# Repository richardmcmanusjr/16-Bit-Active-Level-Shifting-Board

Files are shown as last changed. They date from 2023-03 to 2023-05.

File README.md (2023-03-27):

# 16-Bit-Active-Level-Shifting-Board

This repository contains a 16-bit active level shifting board designed to interface a 16-bit adiabatic MIPS with a Virtex-7 VC707 FPGA. Active level shifting was required to convert the FPGA's 0 to +1.8V logic to the microprocessor's -0.6 to +0.6V logic. Comparators and a direction control unit was chosen for this purpose.

# Details

Schematic File:
  - 1-bit level shifting design block replicated 16 times
  - Power design block for regulated +/-1.5V and +3V
  - Direction controlling design block
  
Board File:
  - 2 layer board
  - 2 columns of 8 level shifting design blocks
  - 24-pin Molex ribbon cable connectors for input/output
  
# Design

### 1-Bit Active Level Shifter
<p align="center">
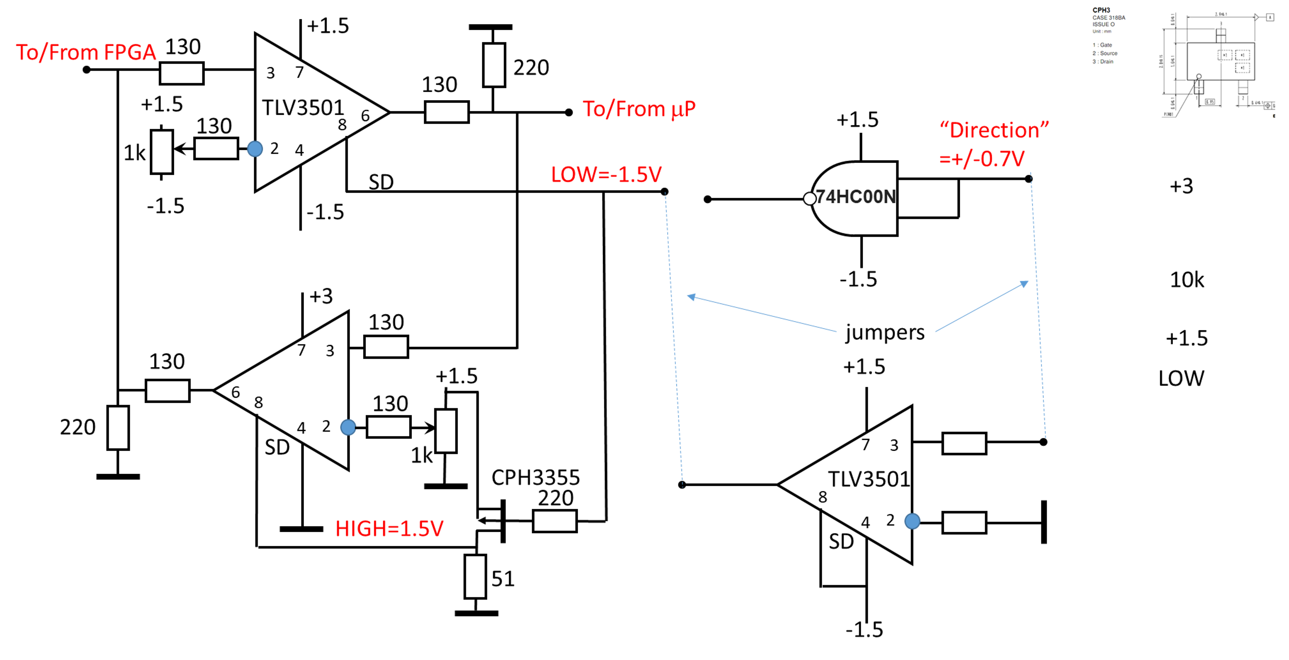
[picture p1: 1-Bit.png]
  
</p>

# Layout 

### mainboard-01-8x2+1c.brd
<p align="center">
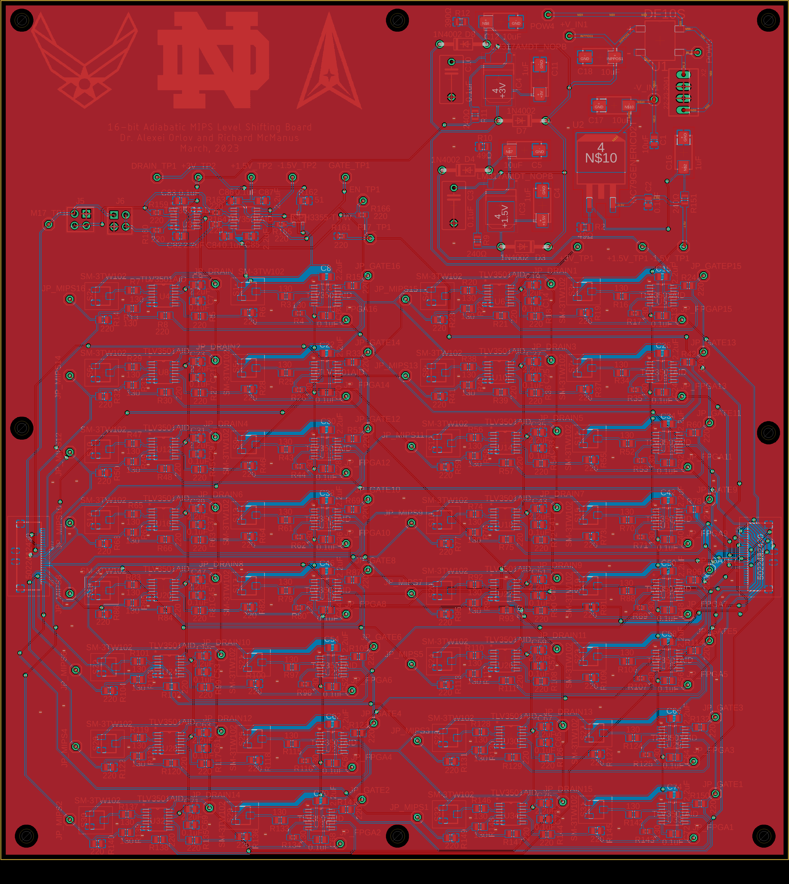
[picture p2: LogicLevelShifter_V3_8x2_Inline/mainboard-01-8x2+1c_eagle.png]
  
</p>

### mainboard-01-8x2+1c OSHPARK
<p align="center">
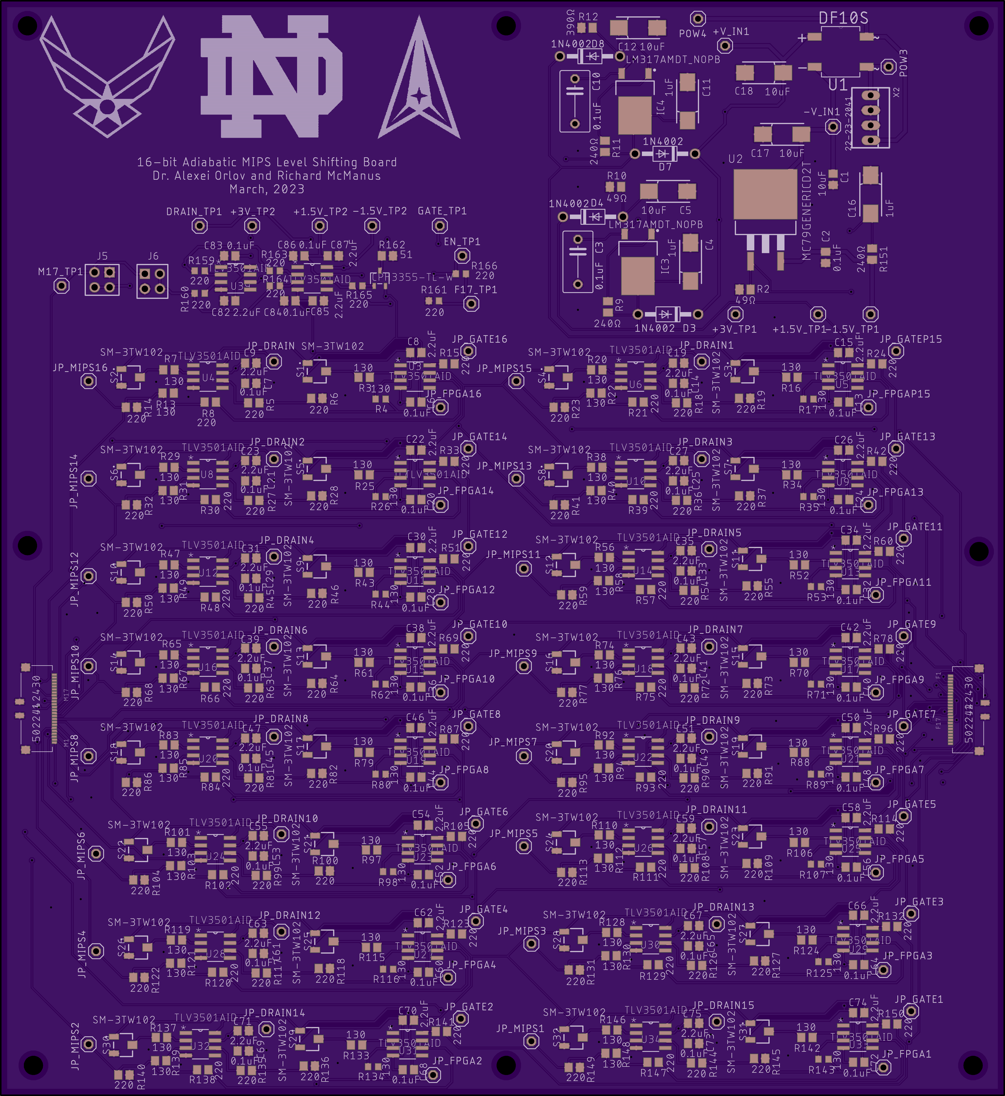
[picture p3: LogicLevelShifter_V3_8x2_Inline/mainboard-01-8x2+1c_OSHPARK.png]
  
</p>

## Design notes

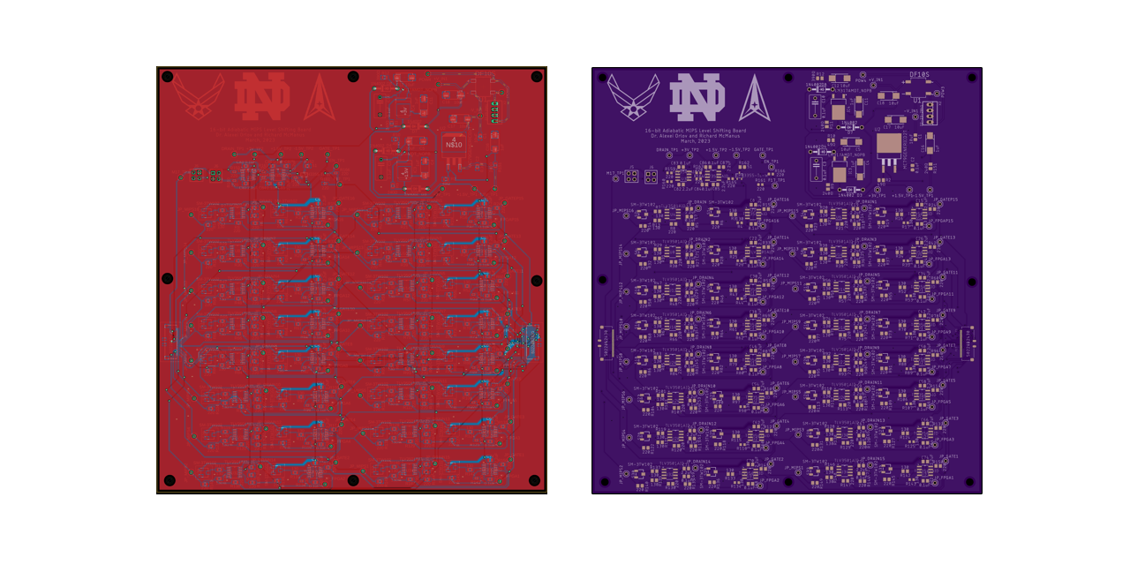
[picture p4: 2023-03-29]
preview.png

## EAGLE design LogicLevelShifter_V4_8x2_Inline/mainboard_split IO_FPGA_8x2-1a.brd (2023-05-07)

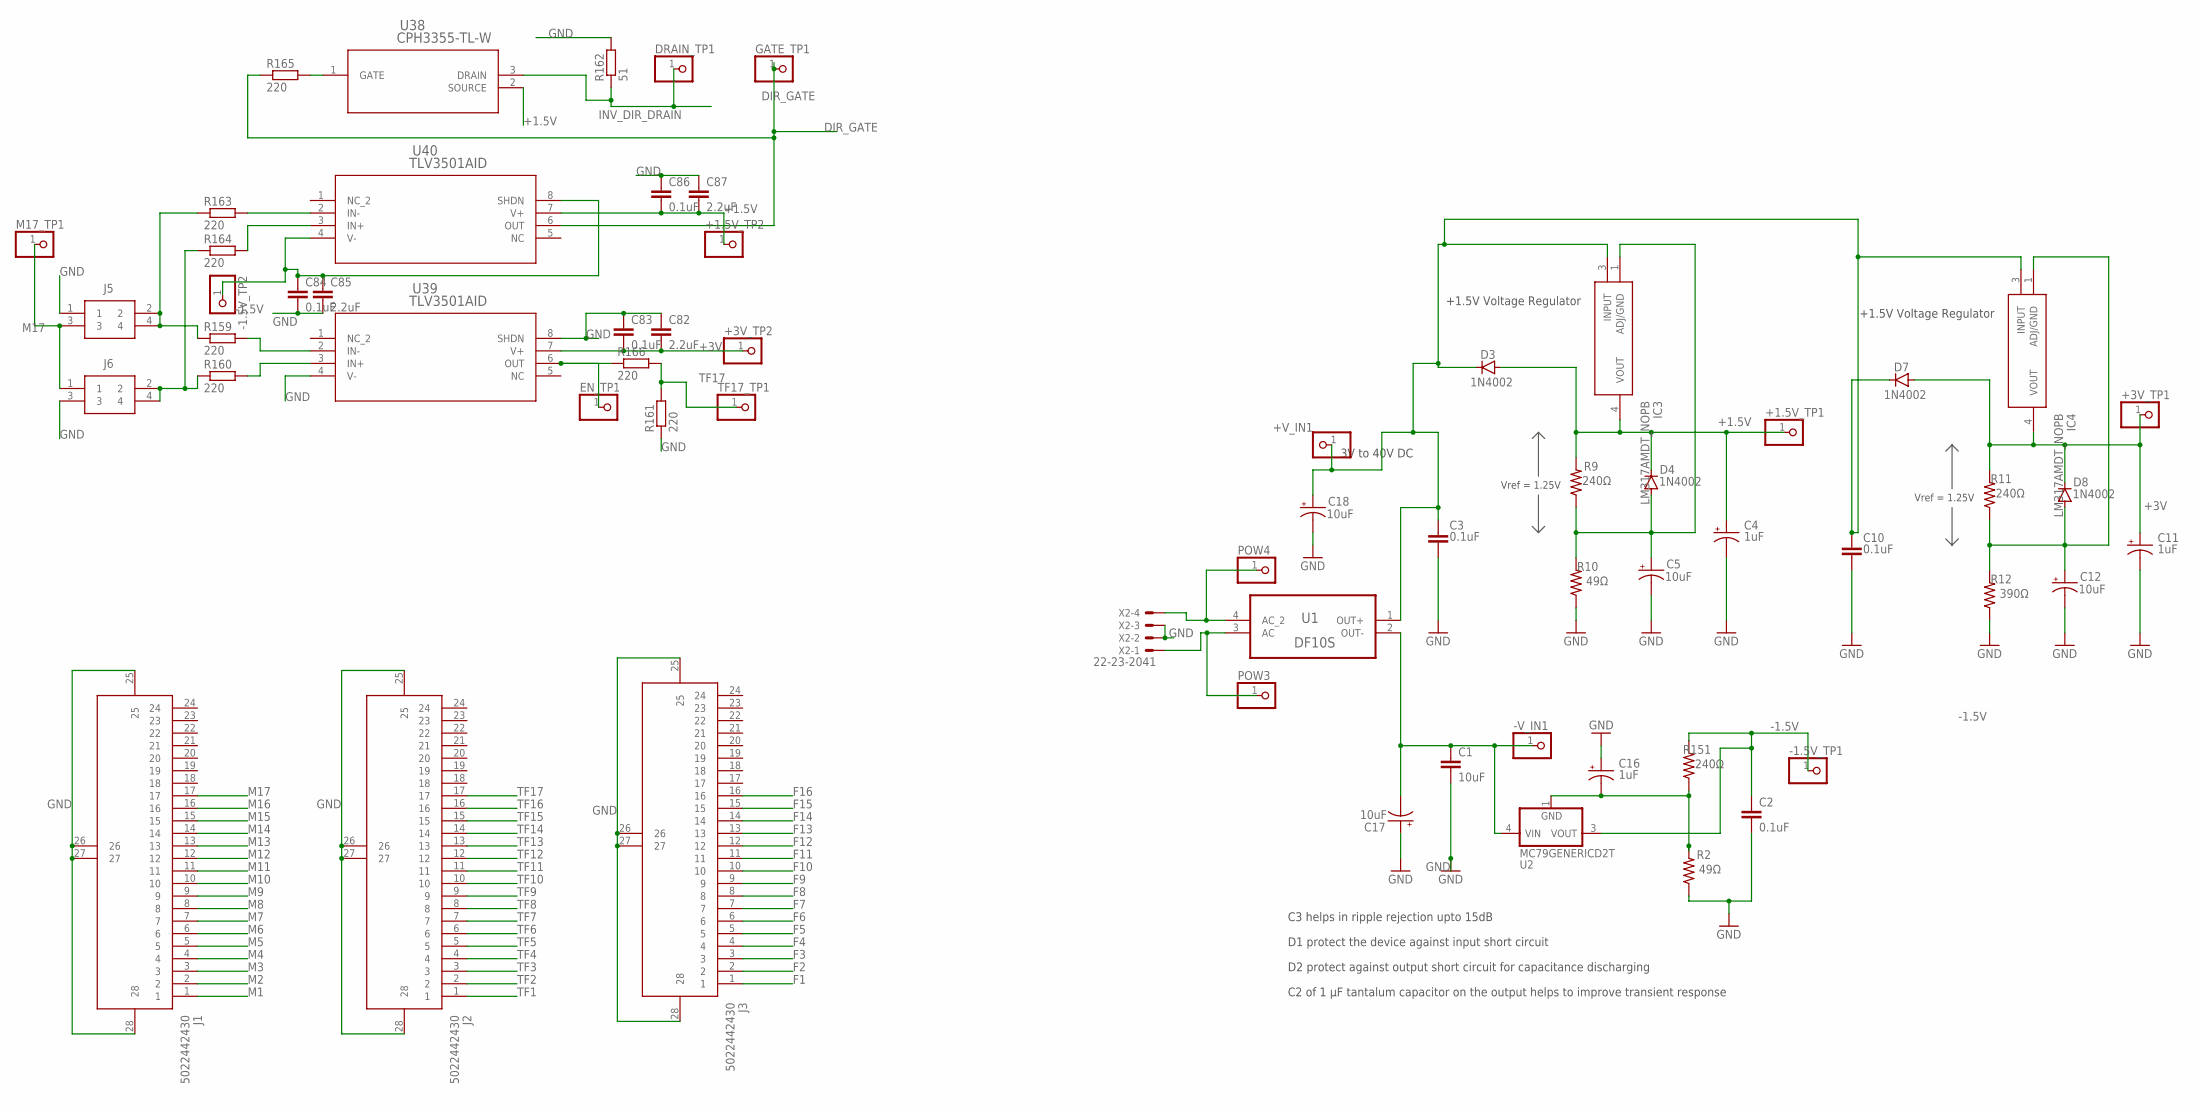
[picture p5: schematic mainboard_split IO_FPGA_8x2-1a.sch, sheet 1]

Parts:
+1.5V_TP1, +1.5V_TP2, +3V_TP1, +3V_TP2: PINHD-1X1; 1X01
+V_IN1: PINHD-1X1; 1X01
-1.5V_TP1, -1.5V_TP2: PINHD-1X1; 1X01
-V_IN1: PINHD-1X1; 1X01
C1: 10uF; C0805
C2, C83, C84, C86: 0.1uF; C0805
C3, C10: 0.1uF; C075-052X106
C4, C11, C16: 1uF; 085CS_1AR
C5, C12, C17, C18: 10uF; 085CS_1AR
C82, C85, C87: 2.2uF; C0805
D3, D4, D7, D8: 1N4002; DO41-10
DRAIN_TP1: PINHD-1X1; 1X01
EN_TP1: PINHD-1X1; 1X01
GATE_TP1: PINHD-1X1; 1X01
IC3, IC4: LM317AMDT_NOPB; TO228P991X238-3N
J1, J2, J3: 5022442430
J5, J6: 70287-1098; HDRV4W64P254_2X2_521X508X851P
M17_TP1: PINHD-1X1; 1X01
POW3, POW4: PINHD-1X1; 1X01
R2, R10: 49Ω; M0805
R9, R11, R151: 240Ω; M0805
R12: 390Ω; M0805
R159, R160, R161, R163, R164, R165, R166: 220; R0603
R162: 51; R0805
TF17_TP1: PINHD-1X1; 1X01
U1: DF10S; SOT508P985X260-4N
U2: MC79GENERICD2T; D2PAK-3
U38: CPH3355-TL-W; CPH3_2P9X1P6_ONS
U39, U40: TLV3501AID; D8
X2: 22-23-2041

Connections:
+1.5V: +1.5V_TP1.1, +1.5V_TP2.1, C4.+, C86.2, C87.2, D3.A, D4.C, IC3.4 (VOUT), R9.2, U38.2 (SOURCE), U40.7 (V+); also elsewhere on the board
+3V: +3V_TP1.1, +3V_TP2.1, C11.+, C82.2, C83.2, D7.A, D8.C, IC4.4 (VOUT), R11.2, U39.7 (V+); also elsewhere on the board
-1.5V: -1.5V_TP1.1, -1.5V_TP2.1, C2.1, C84.1, C85.1, R151.2, U2.3 (VOUT), U40.4 (V-), U40.8 (SHDN); also elsewhere on the board
DIR_GATE: GATE_TP1.1, R165.1, U40.6 (OUT); also elsewhere on the board
F1: J3.1; also elsewhere on the board
F2: J3.2; also elsewhere on the board
F3: J3.3; also elsewhere on the board
F4: J3.4; also elsewhere on the board
F5: J3.5; also elsewhere on the board
F6: J3.6; also elsewhere on the board
F7: J3.7; also elsewhere on the board
F8: J3.8; also elsewhere on the board
F9: J3.9; also elsewhere on the board
F10: J3.10; also elsewhere on the board
F11: J3.11; also elsewhere on the board
F12: J3.12; also elsewhere on the board
F13: J3.13; also elsewhere on the board
F14: J3.14; also elsewhere on the board
F15: J3.15; also elsewhere on the board
F16: J3.16; also elsewhere on the board
GND: C1.2, C2.2, C3.2, C4.-, C5.-, C10.2, C11.-, C12.-, C16.+, C17.+, C18.-, C82.1, C83.1, C84.2, C85.2, C86.1, C87.1, J1.25, J1.26, J1.27, J1.28, J2.25, J2.26, J2.27, J2.28, J3.25, J3.26, J3.27, J3.28, J5.1, J6.3, R2.1, R10.1, R12.1, R161.1, R162.2, U39.4 (V-), U39.8 (SHDN), X2.2, X2.3; also elsewhere on the board
INPPOS1: +V_IN1.1, C3.1, C10.1, C18.+, D3.C, D7.C, IC3.3 (INPUT), IC4.3 (INPUT), U1.1 (OUT+)
INV_DIR_DRAIN: DRAIN_TP1.1, R162.1, U38.3 (DRAIN); also elsewhere on the board
IN_2: POW3.1, U1.3 (AC), X2.1
M1: J1.1; also elsewhere on the board
M2: J1.2; also elsewhere on the board
M3: J1.3; also elsewhere on the board
M4: J1.4; also elsewhere on the board
M5: J1.5; also elsewhere on the board
M6: J1.6; also elsewhere on the board
M7: J1.7; also elsewhere on the board
M8: J1.8; also elsewhere on the board
M9: J1.9; also elsewhere on the board
M10: J1.10; also elsewhere on the board
M11: J1.11; also elsewhere on the board
M12: J1.12; also elsewhere on the board
M13: J1.13; also elsewhere on the board
M14: J1.14; also elsewhere on the board
M15: J1.15; also elsewhere on the board
M16: J1.16; also elsewhere on the board
M17: J1.17, J5.3, J6.1, M17_TP1.1
unnamed: C16.-, R2.2, R151.1, U2.1 (GND)
unnamed: C5.+, D4.A, IC3.1 (ADJ/GND), R9.1, R10.2
unnamed: C12.+, D8.A, IC4.1 (ADJ/GND), R11.1, R12.2
unnamed: POW4.1, U1.4 (AC_2), X2.4
unnamed: -V_IN1.1, C1.1, C17.-, U1.2 (OUT-), U2.4 (VIN)
unnamed: R159.2, U39.2 (IN-)
unnamed: R160.2, U39.3 (IN+)
unnamed: EN_TP1.1, R166.1, U39.6 (OUT)
unnamed: J6.2, J6.4, R160.1, R164.1
unnamed: J5.2, J5.4, R159.1, R163.1
unnamed: R163.2, U40.2 (IN-)
unnamed: R164.2, U40.3 (IN+)
unnamed: R165.2, U38.1 (GATE)
TF1: J2.1; also elsewhere on the board
TF2: J2.2; also elsewhere on the board
TF3: J2.3; also elsewhere on the board
TF4: J2.4; also elsewhere on the board
TF5: J2.5; also elsewhere on the board
TF6: J2.6; also elsewhere on the board
TF7: J2.7; also elsewhere on the board
TF8: J2.8; also elsewhere on the board
TF9: J2.9; also elsewhere on the board
TF10: J2.10; also elsewhere on the board
TF11: J2.11; also elsewhere on the board
TF12: J2.12; also elsewhere on the board
TF13: J2.13; also elsewhere on the board
TF14: J2.14; also elsewhere on the board
TF15: J2.15; also elsewhere on the board
TF16: J2.16; also elsewhere on the board
TF17: J2.17, R161.2, R166.2, TF17_TP1.1

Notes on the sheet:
+1.5V Voltage Regulator
3V to 40V DC
Vref = 1.25V
C3 helps in ripple rejection upto 15dB
D1 protect the device against input short circuit
D2 protect against output short circuit for capacitance discharging
C2 of 1 µF tantalum capacitor on the output helps to improve transient response

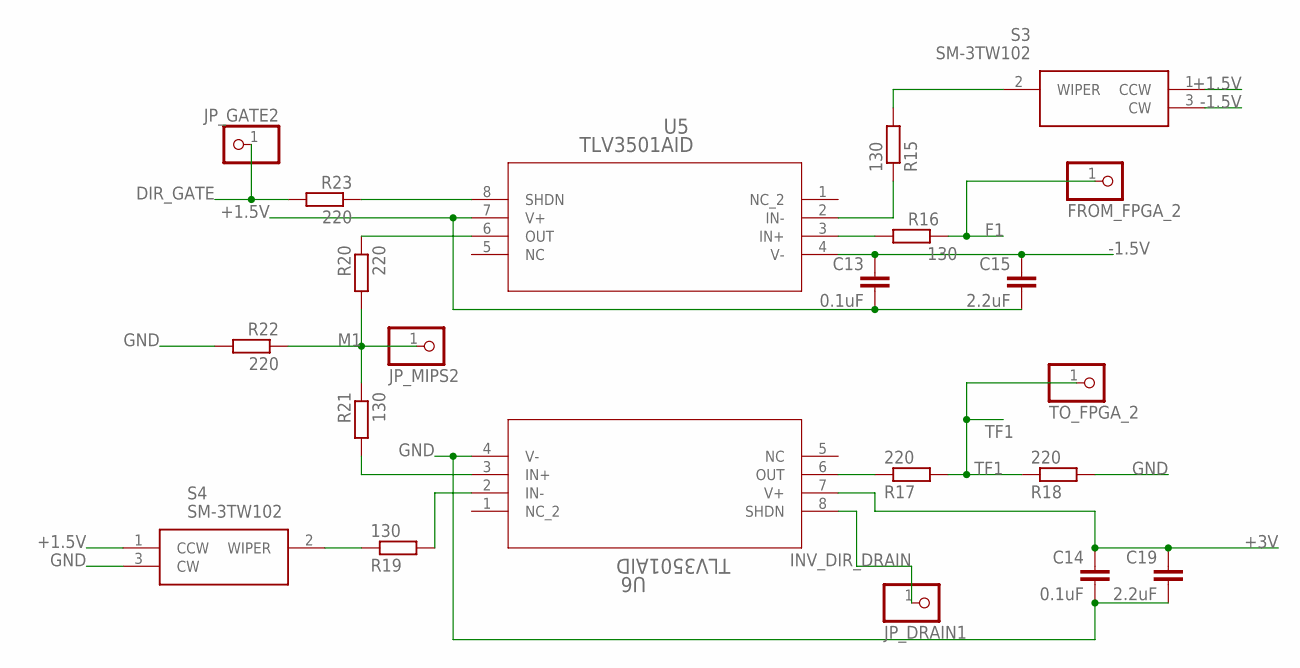
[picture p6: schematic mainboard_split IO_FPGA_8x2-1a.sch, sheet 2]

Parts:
C13, C14: 0.1uF; C0805
C15, C19: 2.2uF; C0805
FROM_FPGA_2: PINHD-1X1; 1X01
JP_DRAIN1: PINHD-1X1; 1X01
JP_GATE2: PINHD-1X1; 1X01
JP_MIPS2: PINHD-1X1; 1X01
R15, R19, R21: 130; R0805
R16: 130; R0603
R17, R18, R20, R22, R23: 220; R0805
S3, S4: SM-3TW102; SM3TW102
TO_FPGA_2: PINHD-1X1; 1X01
U5, U6: TLV3501AID; D8

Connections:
+1.5V: C13.2, C15.2, S3.1 (CCW), S4.1 (CCW), U5.7 (V+); also elsewhere on the board
+3V: C14.1, C19.1, U6.7 (V+); also elsewhere on the board
-1.5V: C13.1, C15.1, S3.3 (CW), U5.4 (V-); also elsewhere on the board
DIR_GATE: JP_GATE2.1, R23.2; also elsewhere on the board
F1: FROM_FPGA_2.1, R16.1; also elsewhere on the board
GND: C14.2, C19.2, R18.2, R22.2, S4.3 (CW), U6.4 (V-); also elsewhere on the board
INV_DIR_DRAIN: JP_DRAIN1.1, U6.8 (SHDN); also elsewhere on the board
M1: JP_MIPS2.1, R20.2, R21.1, R22.1; also elsewhere on the board
unnamed: R15.2, S3.2 (WIPER)
unnamed: R15.1, U5.2 (IN-)
unnamed: R17.1, U6.6 (OUT)
unnamed: R19.1, S4.2 (WIPER)
unnamed: R19.2, U6.2 (IN-)
unnamed: R21.2, U6.3 (IN+)
unnamed: R20.1, U5.6 (OUT)
unnamed: R23.1, U5.8 (SHDN)
unnamed: R16.2, U5.3 (IN+)
TF1: R17.2, R18.1, TO_FPGA_2.1; also elsewhere on the board

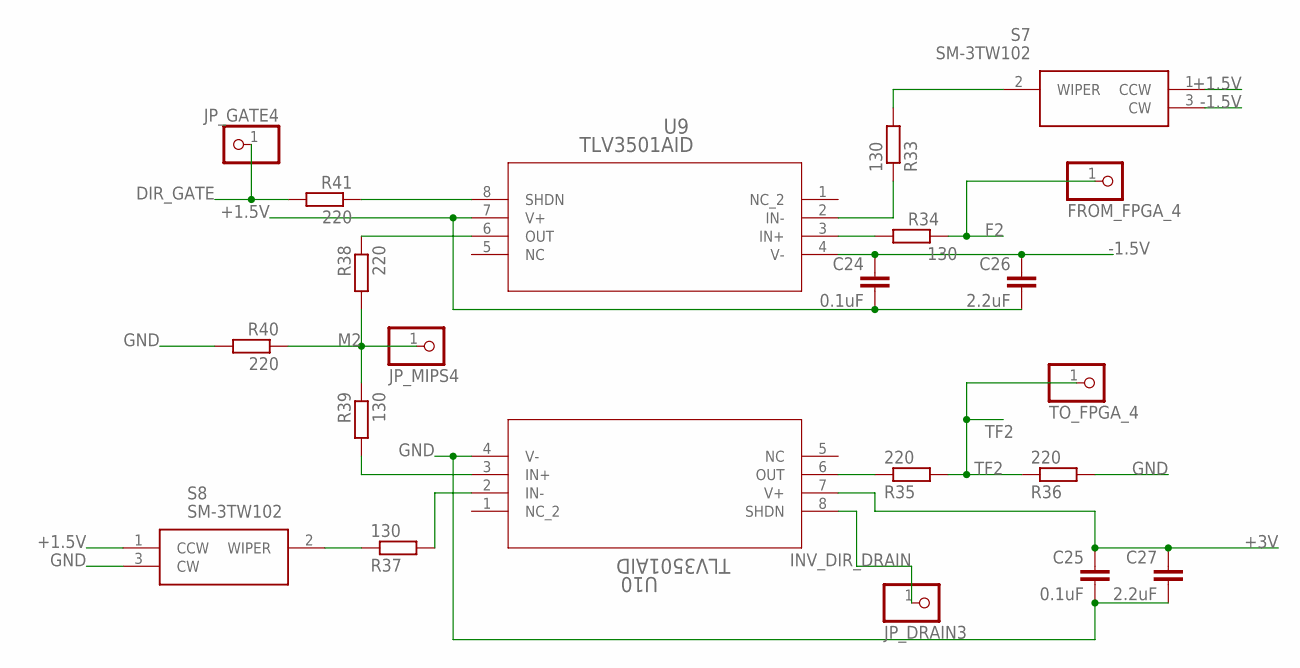
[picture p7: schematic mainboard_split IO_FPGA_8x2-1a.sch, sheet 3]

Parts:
C24, C25: 0.1uF; C0805
C26, C27: 2.2uF; C0805
FROM_FPGA_4: PINHD-1X1; 1X01
JP_DRAIN3: PINHD-1X1; 1X01
JP_GATE4: PINHD-1X1; 1X01
JP_MIPS4: PINHD-1X1; 1X01
R33, R37, R39: 130; R0805
R34: 130; R0603
R35, R36, R38, R40, R41: 220; R0805
S7, S8: SM-3TW102; SM3TW102
TO_FPGA_4: PINHD-1X1; 1X01
U9, U10: TLV3501AID; D8

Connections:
+1.5V: C24.2, C26.2, S7.1 (CCW), S8.1 (CCW), U9.7 (V+); also elsewhere on the board
+3V: C25.1, C27.1, U10.7 (V+); also elsewhere on the board
-1.5V: C24.1, C26.1, S7.3 (CW), U9.4 (V-); also elsewhere on the board
DIR_GATE: JP_GATE4.1, R41.2; also elsewhere on the board
F2: FROM_FPGA_4.1, R34.1; also elsewhere on the board
GND: C25.2, C27.2, R36.2, R40.2, S8.3 (CW), U10.4 (V-); also elsewhere on the board
INV_DIR_DRAIN: JP_DRAIN3.1, U10.8 (SHDN); also elsewhere on the board
M2: JP_MIPS4.1, R38.2, R39.1, R40.1; also elsewhere on the board
unnamed: R33.2, S7.2 (WIPER)
unnamed: R33.1, U9.2 (IN-)
unnamed: R35.1, U10.6 (OUT)
unnamed: R37.1, S8.2 (WIPER)
unnamed: R37.2, U10.2 (IN-)
unnamed: R39.2, U10.3 (IN+)
unnamed: R38.1, U9.6 (OUT)
unnamed: R41.1, U9.8 (SHDN)
unnamed: R34.2, U9.3 (IN+)
TF2: R35.2, R36.1, TO_FPGA_4.1; also elsewhere on the board

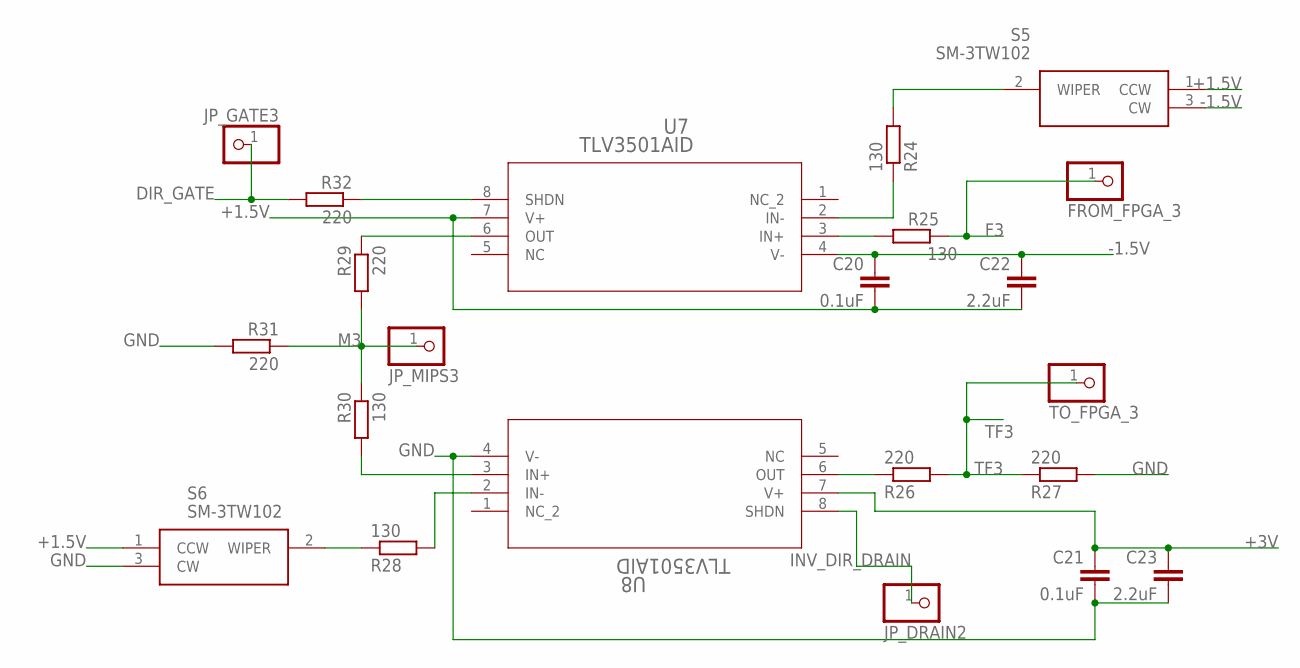
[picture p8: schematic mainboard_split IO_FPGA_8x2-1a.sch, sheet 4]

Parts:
C20, C21: 0.1uF; C0805
C22, C23: 2.2uF; C0805
FROM_FPGA_3: PINHD-1X1; 1X01
JP_DRAIN2: PINHD-1X1; 1X01
JP_GATE3: PINHD-1X1; 1X01
JP_MIPS3: PINHD-1X1; 1X01
R24, R28, R30: 130; R0805
R25: 130; R0603
R26, R27, R29, R31, R32: 220; R0805
S5, S6: SM-3TW102; SM3TW102
TO_FPGA_3: PINHD-1X1; 1X01
U7, U8: TLV3501AID; D8

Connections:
+1.5V: C20.2, C22.2, S5.1 (CCW), S6.1 (CCW), U7.7 (V+); also elsewhere on the board
+3V: C21.1, C23.1, U8.7 (V+); also elsewhere on the board
-1.5V: C20.1, C22.1, S5.3 (CW), U7.4 (V-); also elsewhere on the board
DIR_GATE: JP_GATE3.1, R32.2; also elsewhere on the board
F3: FROM_FPGA_3.1, R25.1; also elsewhere on the board
GND: C21.2, C23.2, R27.2, R31.2, S6.3 (CW), U8.4 (V-); also elsewhere on the board
INV_DIR_DRAIN: JP_DRAIN2.1, U8.8 (SHDN); also elsewhere on the board
M3: JP_MIPS3.1, R29.2, R30.1, R31.1; also elsewhere on the board
unnamed: R24.2, S5.2 (WIPER)
unnamed: R24.1, U7.2 (IN-)
unnamed: R26.1, U8.6 (OUT)
unnamed: R28.1, S6.2 (WIPER)
unnamed: R28.2, U8.2 (IN-)
unnamed: R30.2, U8.3 (IN+)
unnamed: R29.1, U7.6 (OUT)
unnamed: R32.1, U7.8 (SHDN)
unnamed: R25.2, U7.3 (IN+)
TF3: R26.2, R27.1, TO_FPGA_3.1; also elsewhere on the board

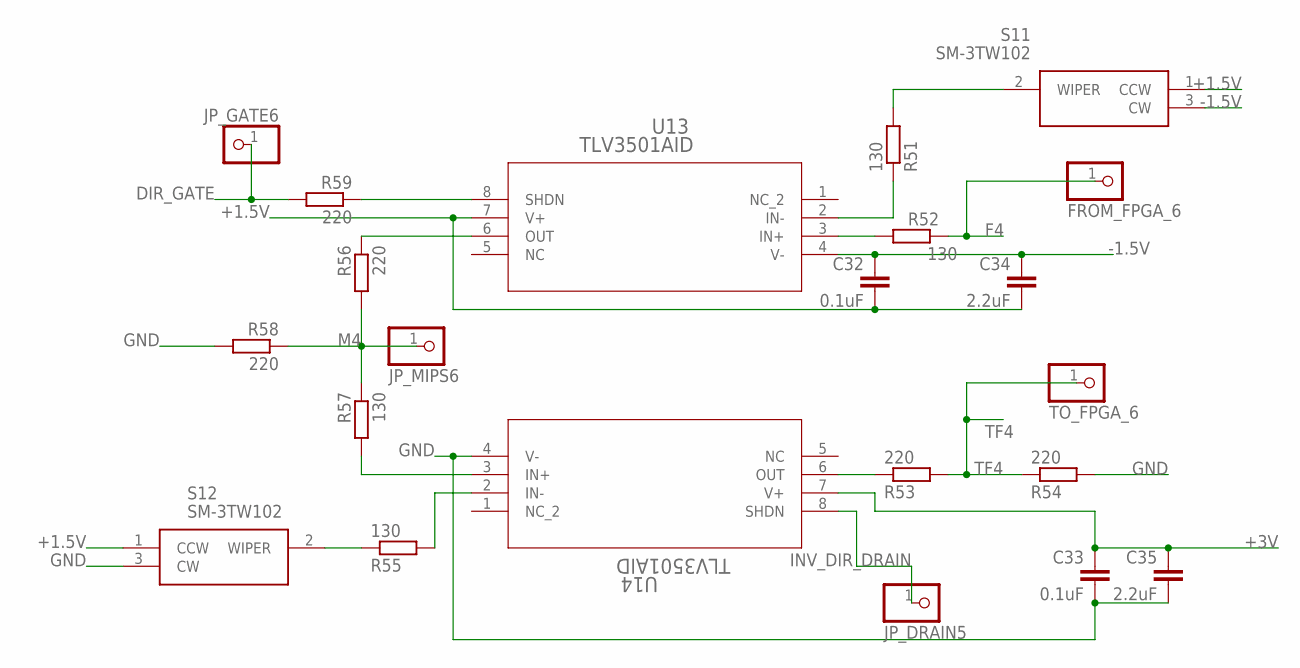
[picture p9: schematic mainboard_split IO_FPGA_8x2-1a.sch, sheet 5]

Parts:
C32, C33: 0.1uF; C0805
C34, C35: 2.2uF; C0805
FROM_FPGA_6: PINHD-1X1; 1X01
JP_DRAIN5: PINHD-1X1; 1X01
JP_GATE6: PINHD-1X1; 1X01
JP_MIPS6: PINHD-1X1; 1X01
R51, R55, R57: 130; R0805
R52: 130; R0603
R53, R54, R56, R58, R59: 220; R0805
S11, S12: SM-3TW102; SM3TW102
TO_FPGA_6: PINHD-1X1; 1X01
U13, U14: TLV3501AID; D8

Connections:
+1.5V: C32.2, C34.2, S11.1 (CCW), S12.1 (CCW), U13.7 (V+); also elsewhere on the board
+3V: C33.1, C35.1, U14.7 (V+); also elsewhere on the board
-1.5V: C32.1, C34.1, S11.3 (CW), U13.4 (V-); also elsewhere on the board
DIR_GATE: JP_GATE6.1, R59.2; also elsewhere on the board
F4: FROM_FPGA_6.1, R52.1; also elsewhere on the board
GND: C33.2, C35.2, R54.2, R58.2, S12.3 (CW), U14.4 (V-); also elsewhere on the board
INV_DIR_DRAIN: JP_DRAIN5.1, U14.8 (SHDN); also elsewhere on the board
M4: JP_MIPS6.1, R56.2, R57.1, R58.1; also elsewhere on the board
unnamed: R51.2, S11.2 (WIPER)
unnamed: R51.1, U13.2 (IN-)
unnamed: R53.1, U14.6 (OUT)
unnamed: R55.1, S12.2 (WIPER)
unnamed: R55.2, U14.2 (IN-)
unnamed: R57.2, U14.3 (IN+)
unnamed: R56.1, U13.6 (OUT)
unnamed: R59.1, U13.8 (SHDN)
unnamed: R52.2, U13.3 (IN+)
TF4: R53.2, R54.1, TO_FPGA_6.1; also elsewhere on the board

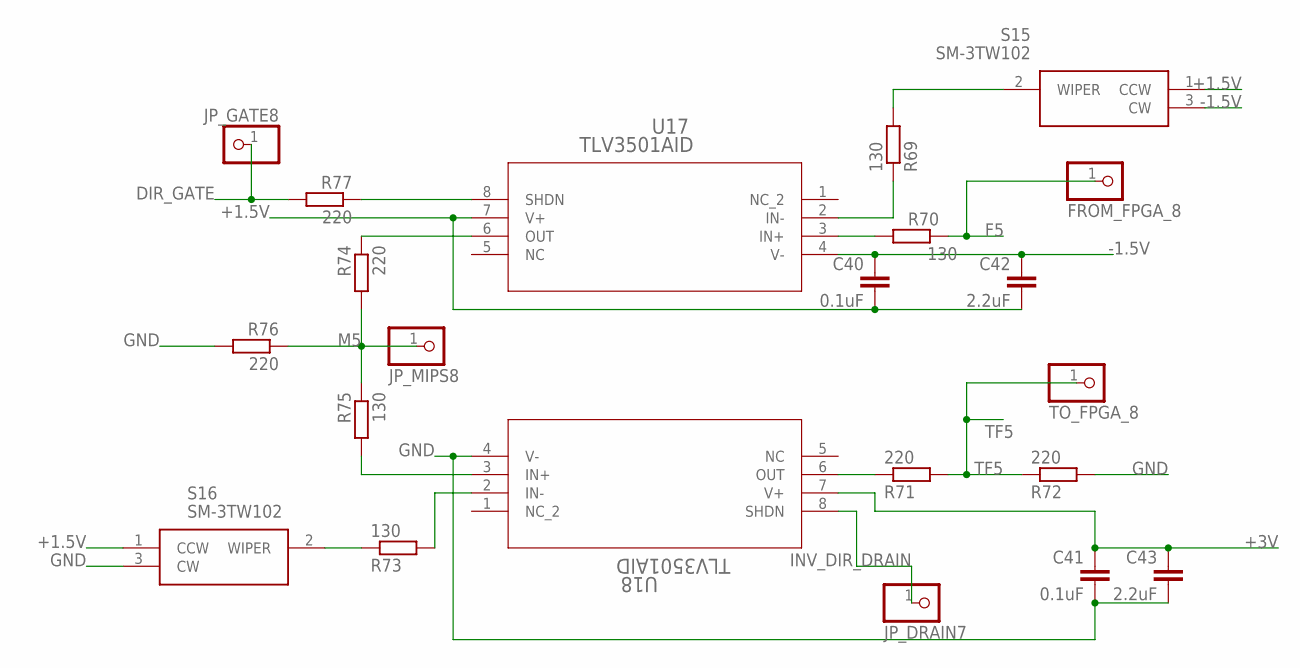
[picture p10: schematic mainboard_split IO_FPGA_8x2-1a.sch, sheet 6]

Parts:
C40, C41: 0.1uF; C0805
C42, C43: 2.2uF; C0805
FROM_FPGA_8: PINHD-1X1; 1X01
JP_DRAIN7: PINHD-1X1; 1X01
JP_GATE8: PINHD-1X1; 1X01
JP_MIPS8: PINHD-1X1; 1X01
R69, R73, R75: 130; R0805
R70: 130; R0603
R71, R72, R74, R76, R77: 220; R0805
S15, S16: SM-3TW102; SM3TW102
TO_FPGA_8: PINHD-1X1; 1X01
U17, U18: TLV3501AID; D8

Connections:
+1.5V: C40.2, C42.2, S15.1 (CCW), S16.1 (CCW), U17.7 (V+); also elsewhere on the board
+3V: C41.1, C43.1, U18.7 (V+); also elsewhere on the board
-1.5V: C40.1, C42.1, S15.3 (CW), U17.4 (V-); also elsewhere on the board
DIR_GATE: JP_GATE8.1, R77.2; also elsewhere on the board
F5: FROM_FPGA_8.1, R70.1; also elsewhere on the board
GND: C41.2, C43.2, R72.2, R76.2, S16.3 (CW), U18.4 (V-); also elsewhere on the board
INV_DIR_DRAIN: JP_DRAIN7.1, U18.8 (SHDN); also elsewhere on the board
M5: JP_MIPS8.1, R74.2, R75.1, R76.1; also elsewhere on the board
unnamed: R69.2, S15.2 (WIPER)
unnamed: R69.1, U17.2 (IN-)
unnamed: R71.1, U18.6 (OUT)
unnamed: R73.1, S16.2 (WIPER)
unnamed: R73.2, U18.2 (IN-)
unnamed: R75.2, U18.3 (IN+)
unnamed: R74.1, U17.6 (OUT)
unnamed: R77.1, U17.8 (SHDN)
unnamed: R70.2, U17.3 (IN+)
TF5: R71.2, R72.1, TO_FPGA_8.1; also elsewhere on the board

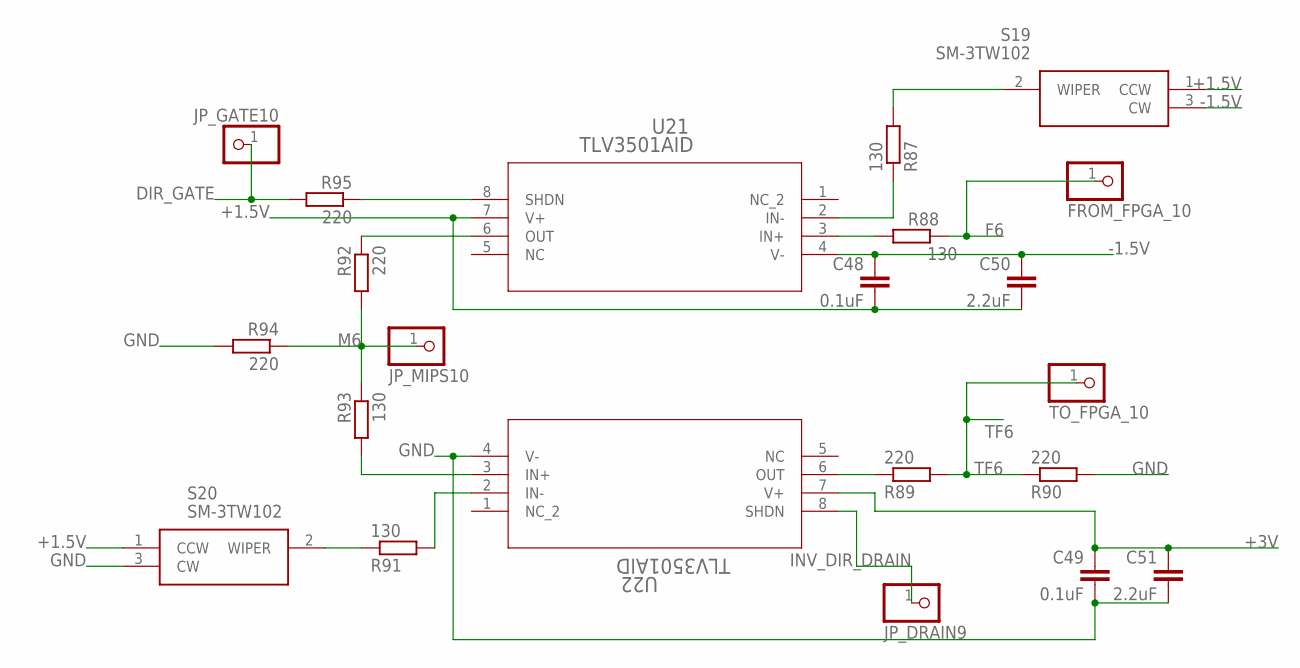
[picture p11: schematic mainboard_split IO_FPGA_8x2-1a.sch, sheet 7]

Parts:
C48, C49: 0.1uF; C0805
C50, C51: 2.2uF; C0805
FROM_FPGA_10: PINHD-1X1; 1X01
JP_DRAIN9: PINHD-1X1; 1X01
JP_GATE10: PINHD-1X1; 1X01
JP_MIPS10: PINHD-1X1; 1X01
R87, R91, R93: 130; R0805
R88: 130; R0603
R89, R90, R92, R94, R95: 220; R0805
S19, S20: SM-3TW102; SM3TW102
TO_FPGA_10: PINHD-1X1; 1X01
U21, U22: TLV3501AID; D8

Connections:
+1.5V: C48.2, C50.2, S19.1 (CCW), S20.1 (CCW), U21.7 (V+); also elsewhere on the board
+3V: C49.1, C51.1, U22.7 (V+); also elsewhere on the board
-1.5V: C48.1, C50.1, S19.3 (CW), U21.4 (V-); also elsewhere on the board
DIR_GATE: JP_GATE10.1, R95.2; also elsewhere on the board
F6: FROM_FPGA_10.1, R88.1; also elsewhere on the board
GND: C49.2, C51.2, R90.2, R94.2, S20.3 (CW), U22.4 (V-); also elsewhere on the board
INV_DIR_DRAIN: JP_DRAIN9.1, U22.8 (SHDN); also elsewhere on the board
M6: JP_MIPS10.1, R92.2, R93.1, R94.1; also elsewhere on the board
unnamed: R87.2, S19.2 (WIPER)
unnamed: R87.1, U21.2 (IN-)
unnamed: R89.1, U22.6 (OUT)
unnamed: R91.1, S20.2 (WIPER)
unnamed: R91.2, U22.2 (IN-)
unnamed: R93.2, U22.3 (IN+)
unnamed: R92.1, U21.6 (OUT)
unnamed: R95.1, U21.8 (SHDN)
unnamed: R88.2, U21.3 (IN+)
TF6: R89.2, R90.1, TO_FPGA_10.1; also elsewhere on the board

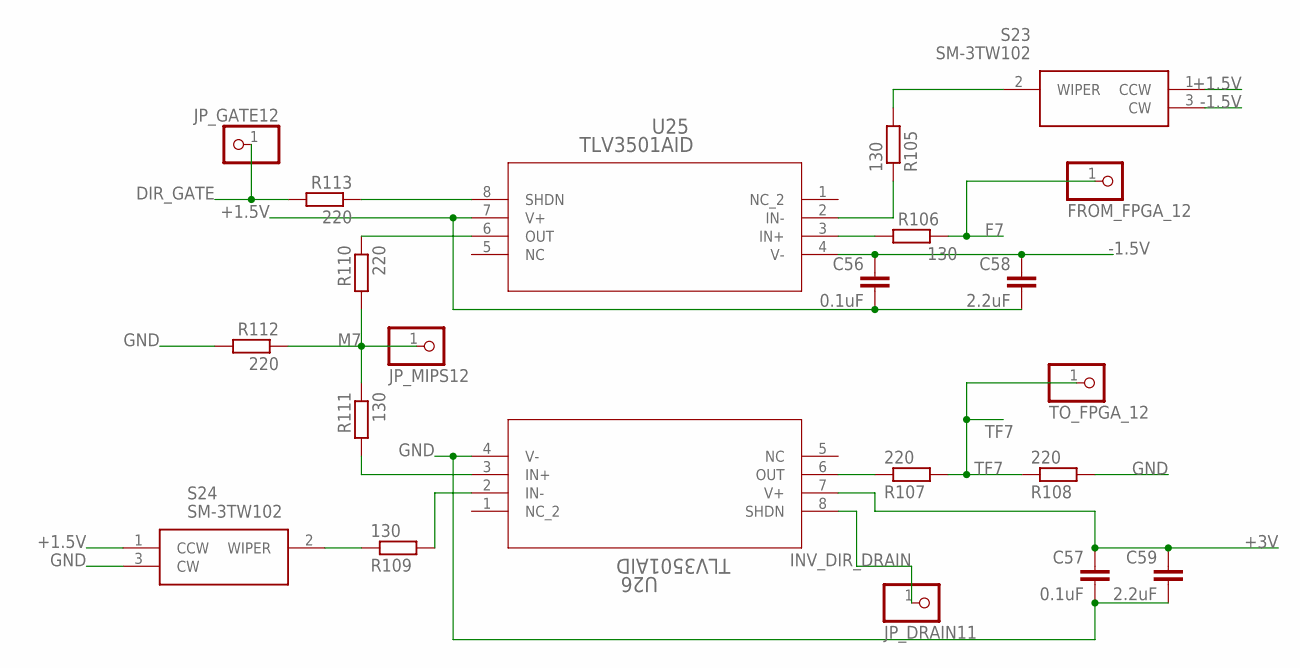
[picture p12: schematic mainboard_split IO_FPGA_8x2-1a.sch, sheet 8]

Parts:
C56, C57: 0.1uF; C0805
C58, C59: 2.2uF; C0805
FROM_FPGA_12: PINHD-1X1; 1X01
JP_DRAIN11: PINHD-1X1; 1X01
JP_GATE12: PINHD-1X1; 1X01
JP_MIPS12: PINHD-1X1; 1X01
R105, R109, R111: 130; R0805
R106: 130; R0603
R107, R108, R110, R112, R113: 220; R0805
S23, S24: SM-3TW102; SM3TW102
TO_FPGA_12: PINHD-1X1; 1X01
U25, U26: TLV3501AID; D8

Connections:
+1.5V: C56.2, C58.2, S23.1 (CCW), S24.1 (CCW), U25.7 (V+); also elsewhere on the board
+3V: C57.1, C59.1, U26.7 (V+); also elsewhere on the board
-1.5V: C56.1, C58.1, S23.3 (CW), U25.4 (V-); also elsewhere on the board
DIR_GATE: JP_GATE12.1, R113.2; also elsewhere on the board
F7: FROM_FPGA_12.1, R106.1; also elsewhere on the board
GND: C57.2, C59.2, R108.2, R112.2, S24.3 (CW), U26.4 (V-); also elsewhere on the board
INV_DIR_DRAIN: JP_DRAIN11.1, U26.8 (SHDN); also elsewhere on the board
M7: JP_MIPS12.1, R110.2, R111.1, R112.1; also elsewhere on the board
unnamed: R105.2, S23.2 (WIPER)
unnamed: R105.1, U25.2 (IN-)
unnamed: R107.1, U26.6 (OUT)
unnamed: R109.1, S24.2 (WIPER)
unnamed: R109.2, U26.2 (IN-)
unnamed: R111.2, U26.3 (IN+)
unnamed: R110.1, U25.6 (OUT)
unnamed: R113.1, U25.8 (SHDN)
unnamed: R106.2, U25.3 (IN+)
TF7: R107.2, R108.1, TO_FPGA_12.1; also elsewhere on the board

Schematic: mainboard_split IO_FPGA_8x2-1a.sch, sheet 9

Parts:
C64, C65: 0.1uF; C0805
C66, C67: 2.2uF; C0805
FROM_FPGA_14: PINHD-1X1; 1X01
JP_DRAIN13: PINHD-1X1; 1X01
JP_GATE14: PINHD-1X1; 1X01
JP_MIPS14: PINHD-1X1; 1X01
R123, R127, R129: 130; R0805
R124: 130; R0603
R125, R126, R128, R130, R131: 220; R0805
S27, S28: SM-3TW102; SM3TW102
TO_FPGA_14: PINHD-1X1; 1X01
U29, U30: TLV3501AID; D8

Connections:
+1.5V: C64.2, C66.2, S27.1 (CCW), S28.1 (CCW), U29.7 (V+); also elsewhere on the board
+3V: C65.1, C67.1, U30.7 (V+); also elsewhere on the board
-1.5V: C64.1, C66.1, S27.3 (CW), U29.4 (V-); also elsewhere on the board
DIR_GATE: JP_GATE14.1, R131.2; also elsewhere on the board
F8: FROM_FPGA_14.1, R124.1; also elsewhere on the board
GND: C65.2, C67.2, R126.2, R130.2, S28.3 (CW), U30.4 (V-); also elsewhere on the board
INV_DIR_DRAIN: JP_DRAIN13.1, U30.8 (SHDN); also elsewhere on the board
M8: JP_MIPS14.1, R128.2, R129.1, R130.1; also elsewhere on the board
unnamed: R123.2, S27.2 (WIPER)
unnamed: R123.1, U29.2 (IN-)
unnamed: R125.1, U30.6 (OUT)
unnamed: R127.1, S28.2 (WIPER)
unnamed: R127.2, U30.2 (IN-)
unnamed: R129.2, U30.3 (IN+)
unnamed: R128.1, U29.6 (OUT)
unnamed: R131.1, U29.8 (SHDN)
unnamed: R124.2, U29.3 (IN+)
TF8: R125.2, R126.1, TO_FPGA_14.1; also elsewhere on the board

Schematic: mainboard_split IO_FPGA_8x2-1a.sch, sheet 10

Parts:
C72, C73: 0.1uF; C0805
C74, C75: 2.2uF; C0805
FROM_FPGA_16: PINHD-1X1; 1X01
JP_DRAIN15: PINHD-1X1; 1X01
JP_GATE16: PINHD-1X1; 1X01
JP_MIPS16: PINHD-1X1; 1X01
R141, R145, R147: 130; R0805
R142: 130; R0603
R143, R144, R146, R148, R149: 220; R0805
S31, S32: SM-3TW102; SM3TW102
TO_FPGA_16: PINHD-1X1; 1X01
U33, U34: TLV3501AID; D8

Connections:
+1.5V: C72.2, C74.2, S31.1 (CCW), S32.1 (CCW), U33.7 (V+); also elsewhere on the board
+3V: C73.1, C75.1, U34.7 (V+); also elsewhere on the board
-1.5V: C72.1, C74.1, S31.3 (CW), U33.4 (V-); also elsewhere on the board
DIR_GATE: JP_GATE16.1, R149.2; also elsewhere on the board
F9: FROM_FPGA_16.1, R142.1; also elsewhere on the board
GND: C73.2, C75.2, R144.2, R148.2, S32.3 (CW), U34.4 (V-); also elsewhere on the board
INV_DIR_DRAIN: JP_DRAIN15.1, U34.8 (SHDN); also elsewhere on the board
M9: JP_MIPS16.1, R146.2, R147.1, R148.1; also elsewhere on the board
unnamed: R141.2, S31.2 (WIPER)
unnamed: R141.1, U33.2 (IN-)
unnamed: R143.1, U34.6 (OUT)
unnamed: R145.1, S32.2 (WIPER)
unnamed: R145.2, U34.2 (IN-)
unnamed: R147.2, U34.3 (IN+)
unnamed: R146.1, U33.6 (OUT)
unnamed: R149.1, U33.8 (SHDN)
unnamed: R142.2, U33.3 (IN+)
TF9: R143.2, R144.1, TO_FPGA_16.1; also elsewhere on the board

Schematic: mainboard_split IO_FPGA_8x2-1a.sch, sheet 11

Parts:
C80, C81: 0.1uF; C0805
C88, C89: 2.2uF; C0805
FROM_FPGA_18: PINHD-1X1; 1X01
JP_DRAIN17: PINHD-1X1; 1X01
JP_GATE18: PINHD-1X1; 1X01
JP_MIPS18: PINHD-1X1; 1X01
R168, R172, R174: 130; R0805
R169: 130; R0603
R170, R171, R173, R175, R176: 220; R0805
S35, S36: SM-3TW102; SM3TW102
TO_FPGA_18: PINHD-1X1; 1X01
U37, U41: TLV3501AID; D8

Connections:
+1.5V: C80.2, C88.2, S35.1 (CCW), S36.1 (CCW), U37.7 (V+); also elsewhere on the board
+3V: C81.1, C89.1, U41.7 (V+); also elsewhere on the board
-1.5V: C80.1, C88.1, S35.3 (CW), U37.4 (V-); also elsewhere on the board
DIR_GATE: JP_GATE18.1, R176.2; also elsewhere on the board
F10: FROM_FPGA_18.1, R169.1; also elsewhere on the board
GND: C81.2, C89.2, R171.2, R175.2, S36.3 (CW), U41.4 (V-); also elsewhere on the board
INV_DIR_DRAIN: JP_DRAIN17.1, U41.8 (SHDN); also elsewhere on the board
M10: JP_MIPS18.1, R173.2, R174.1, R175.1; also elsewhere on the board
unnamed: R168.2, S35.2 (WIPER)
unnamed: R168.1, U37.2 (IN-)
unnamed: R170.1, U41.6 (OUT)
unnamed: R172.1, S36.2 (WIPER)
unnamed: R172.2, U41.2 (IN-)
unnamed: R174.2, U41.3 (IN+)
unnamed: R173.1, U37.6 (OUT)
unnamed: R176.1, U37.8 (SHDN)
unnamed: R169.2, U37.3 (IN+)
TF10: R170.2, R171.1, TO_FPGA_18.1; also elsewhere on the board

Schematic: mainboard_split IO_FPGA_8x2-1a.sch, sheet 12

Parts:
C28, C29: 0.1uF; C0805
C30, C31: 2.2uF; C0805
FROM_FPGA_5: PINHD-1X1; 1X01
JP_DRAIN4: PINHD-1X1; 1X01
JP_GATE5: PINHD-1X1; 1X01
JP_MIPS5: PINHD-1X1; 1X01
R42, R46, R48: 130; R0805
R43: 130; R0603
R44, R45, R47, R49, R50: 220; R0805
S9, S10: SM-3TW102; SM3TW102
TO_FPGA_5: PINHD-1X1; 1X01
U11, U12: TLV3501AID; D8

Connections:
+1.5V: C28.2, C30.2, S9.1 (CCW), S10.1 (CCW), U11.7 (V+); also elsewhere on the board
+3V: C29.1, C31.1, U12.7 (V+); also elsewhere on the board
-1.5V: C28.1, C30.1, S9.3 (CW), U11.4 (V-); also elsewhere on the board
DIR_GATE: JP_GATE5.1, R50.2; also elsewhere on the board
F11: FROM_FPGA_5.1, R43.1; also elsewhere on the board
GND: C29.2, C31.2, R45.2, R49.2, S10.3 (CW), U12.4 (V-); also elsewhere on the board
INV_DIR_DRAIN: JP_DRAIN4.1, U12.8 (SHDN); also elsewhere on the board
M11: JP_MIPS5.1, R47.2, R48.1, R49.1; also elsewhere on the board
unnamed: R42.2, S9.2 (WIPER)
unnamed: R42.1, U11.2 (IN-)
unnamed: R44.1, U12.6 (OUT)
unnamed: R46.1, S10.2 (WIPER)
unnamed: R46.2, U12.2 (IN-)
unnamed: R48.2, U12.3 (IN+)
unnamed: R47.1, U11.6 (OUT)
unnamed: R50.1, U11.8 (SHDN)
unnamed: R43.2, U11.3 (IN+)
TF11: R44.2, R45.1, TO_FPGA_5.1; also elsewhere on the board

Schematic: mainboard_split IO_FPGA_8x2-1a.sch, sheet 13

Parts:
C44, C45: 0.1uF; C0805
C46, C47: 2.2uF; C0805
FROM_FPGA_9: PINHD-1X1; 1X01
JP_DRAIN8: PINHD-1X1; 1X01
JP_GATE9: PINHD-1X1; 1X01
JP_MIPS9: PINHD-1X1; 1X01
R78, R82, R84: 130; R0805
R79: 130; R0603
R80, R81, R83, R85, R86: 220; R0805
S17, S18: SM-3TW102; SM3TW102
TO_FPGA_9: PINHD-1X1; 1X01
U19, U20: TLV3501AID; D8

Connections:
+1.5V: C44.2, C46.2, S17.1 (CCW), S18.1 (CCW), U19.7 (V+); also elsewhere on the board
+3V: C45.1, C47.1, U20.7 (V+); also elsewhere on the board
-1.5V: C44.1, C46.1, S17.3 (CW), U19.4 (V-); also elsewhere on the board
DIR_GATE: JP_GATE9.1, R86.2; also elsewhere on the board
F12: FROM_FPGA_9.1, R79.1; also elsewhere on the board
GND: C45.2, C47.2, R81.2, R85.2, S18.3 (CW), U20.4 (V-); also elsewhere on the board
INV_DIR_DRAIN: JP_DRAIN8.1, U20.8 (SHDN); also elsewhere on the board
M12: JP_MIPS9.1, R83.2, R84.1, R85.1; also elsewhere on the board
unnamed: R78.2, S17.2 (WIPER)
unnamed: R78.1, U19.2 (IN-)
unnamed: R80.1, U20.6 (OUT)
unnamed: R82.1, S18.2 (WIPER)
unnamed: R82.2, U20.2 (IN-)
unnamed: R84.2, U20.3 (IN+)
unnamed: R83.1, U19.6 (OUT)
unnamed: R86.1, U19.8 (SHDN)
unnamed: R79.2, U19.3 (IN+)
TF12: R80.2, R81.1, TO_FPGA_9.1; also elsewhere on the board

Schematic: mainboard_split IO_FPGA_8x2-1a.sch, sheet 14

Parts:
C36, C37: 0.1uF; C0805
C38, C39: 2.2uF; C0805
FROM_FPGA_7: PINHD-1X1; 1X01
JP_DRAIN6: PINHD-1X1; 1X01
JP_GATE7: PINHD-1X1; 1X01
JP_MIPS7: PINHD-1X1; 1X01
R60, R64, R66: 130; R0805
R61: 130; R0603
R62, R63, R65, R67, R68: 220; R0805
S13, S14: SM-3TW102; SM3TW102
TO_FPGA_7: PINHD-1X1; 1X01
U15, U16: TLV3501AID; D8

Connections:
+1.5V: C36.2, C38.2, S13.1 (CCW), S14.1 (CCW), U15.7 (V+); also elsewhere on the board
+3V: C37.1, C39.1, U16.7 (V+); also elsewhere on the board
-1.5V: C36.1, C38.1, S13.3 (CW), U15.4 (V-); also elsewhere on the board
DIR_GATE: JP_GATE7.1, R68.2; also elsewhere on the board
F13: FROM_FPGA_7.1, R61.1; also elsewhere on the board
GND: C37.2, C39.2, R63.2, R67.2, S14.3 (CW), U16.4 (V-); also elsewhere on the board
INV_DIR_DRAIN: JP_DRAIN6.1, U16.8 (SHDN); also elsewhere on the board
M13: JP_MIPS7.1, R65.2, R66.1, R67.1; also elsewhere on the board
unnamed: R60.2, S13.2 (WIPER)
unnamed: R60.1, U15.2 (IN-)
unnamed: R62.1, U16.6 (OUT)
unnamed: R64.1, S14.2 (WIPER)
unnamed: R64.2, U16.2 (IN-)
unnamed: R66.2, U16.3 (IN+)
unnamed: R65.1, U15.6 (OUT)
unnamed: R68.1, U15.8 (SHDN)
unnamed: R61.2, U15.3 (IN+)
TF13: R62.2, R63.1, TO_FPGA_7.1; also elsewhere on the board

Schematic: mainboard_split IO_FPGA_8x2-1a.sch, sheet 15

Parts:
C60, C61: 0.1uF; C0805
C62, C63: 2.2uF; C0805
FROM_FPGA_13: PINHD-1X1; 1X01
JP_DRAIN12: PINHD-1X1; 1X01
JP_GATE13: PINHD-1X1; 1X01
JP_MIPS13: PINHD-1X1; 1X01
R114, R118, R120: 130; R0805
R115: 130; R0603
R116, R117, R119, R121, R122: 220; R0805
S25, S26: SM-3TW102; SM3TW102
TO_FPGA_13: PINHD-1X1; 1X01
U27, U28: TLV3501AID; D8

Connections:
+1.5V: C60.2, C62.2, S25.1 (CCW), S26.1 (CCW), U27.7 (V+); also elsewhere on the board
+3V: C61.1, C63.1, U28.7 (V+); also elsewhere on the board
-1.5V: C60.1, C62.1, S25.3 (CW), U27.4 (V-); also elsewhere on the board
DIR_GATE: JP_GATE13.1, R122.2; also elsewhere on the board
F14: FROM_FPGA_13.1, R115.1; also elsewhere on the board
GND: C61.2, C63.2, R117.2, R121.2, S26.3 (CW), U28.4 (V-); also elsewhere on the board
INV_DIR_DRAIN: JP_DRAIN12.1, U28.8 (SHDN); also elsewhere on the board
M14: JP_MIPS13.1, R119.2, R120.1, R121.1; also elsewhere on the board
unnamed: R114.2, S25.2 (WIPER)
unnamed: R114.1, U27.2 (IN-)
unnamed: R116.1, U28.6 (OUT)
unnamed: R118.1, S26.2 (WIPER)
unnamed: R118.2, U28.2 (IN-)
unnamed: R120.2, U28.3 (IN+)
unnamed: R119.1, U27.6 (OUT)
unnamed: R122.1, U27.8 (SHDN)
unnamed: R115.2, U27.3 (IN+)
TF14: R116.2, R117.1, TO_FPGA_13.1; also elsewhere on the board

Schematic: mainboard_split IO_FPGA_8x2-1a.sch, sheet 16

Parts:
C76, C77: 0.1uF; C0805
C78, C79: 2.2uF; C0805
FROM_FPGA_17: PINHD-1X1; 1X01
JP_DRAIN16: PINHD-1X1; 1X01
JP_GATE17: PINHD-1X1; 1X01
JP_MIPS17: PINHD-1X1; 1X01
R150, R155, R157: 130; R0805
R152: 130; R0603
R153, R154, R156, R158, R167: 220; R0805
S33, S34: SM-3TW102; SM3TW102
TO_FPGA_17: PINHD-1X1; 1X01
U35, U36: TLV3501AID; D8

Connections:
+1.5V: C76.2, C78.2, S33.1 (CCW), S34.1 (CCW), U35.7 (V+); also elsewhere on the board
+3V: C77.1, C79.1, U36.7 (V+); also elsewhere on the board
-1.5V: C76.1, C78.1, S33.3 (CW), U35.4 (V-); also elsewhere on the board
DIR_GATE: JP_GATE17.1, R167.2; also elsewhere on the board
F15: FROM_FPGA_17.1, R152.1; also elsewhere on the board
GND: C77.2, C79.2, R154.2, R158.2, S34.3 (CW), U36.4 (V-); also elsewhere on the board
INV_DIR_DRAIN: JP_DRAIN16.1, U36.8 (SHDN); also elsewhere on the board
M15: JP_MIPS17.1, R156.2, R157.1, R158.1; also elsewhere on the board
unnamed: R150.2, S33.2 (WIPER)
unnamed: R150.1, U35.2 (IN-)
unnamed: R153.1, U36.6 (OUT)
unnamed: R155.1, S34.2 (WIPER)
unnamed: R155.2, U36.2 (IN-)
unnamed: R157.2, U36.3 (IN+)
unnamed: R156.1, U35.6 (OUT)
unnamed: R167.1, U35.8 (SHDN)
unnamed: R152.2, U35.3 (IN+)
TF15: R153.2, R154.1, TO_FPGA_17.1; also elsewhere on the board

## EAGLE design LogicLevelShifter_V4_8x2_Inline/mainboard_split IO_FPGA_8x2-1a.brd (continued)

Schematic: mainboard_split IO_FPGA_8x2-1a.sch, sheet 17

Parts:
C94, C95: 0.1uF; C0805
C96, C97: 2.2uF; C0805
FROM_FPGA_20: PINHD-1X1; 1X01
JP_DRAIN19: PINHD-1X1; 1X01
JP_GATE20: PINHD-1X1; 1X01
JP_MIPS20: PINHD-1X1; 1X01
R186, R190, R192: 130; R0805
R187: 130; R0603
R188, R189, R191, R193, R194: 220; R0805
S39, S40: SM-3TW102; SM3TW102
TO_FPGA_20: PINHD-1X1; 1X01
U44, U45: TLV3501AID; D8

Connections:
+1.5V: C94.2, C96.2, S39.1 (CCW), S40.1 (CCW), U44.7 (V+); also elsewhere on the board
+3V: C95.1, C97.1, U45.7 (V+); also elsewhere on the board
-1.5V: C94.1, C96.1, S39.3 (CW), U44.4 (V-); also elsewhere on the board
DIR_GATE: JP_GATE20.1, R194.2; also elsewhere on the board
F16: FROM_FPGA_20.1, R187.1; also elsewhere on the board
GND: C95.2, C97.2, R189.2, R193.2, S40.3 (CW), U45.4 (V-); also elsewhere on the board
INV_DIR_DRAIN: JP_DRAIN19.1, U45.8 (SHDN); also elsewhere on the board
M16: JP_MIPS20.1, R191.2, R192.1, R193.1; also elsewhere on the board
unnamed: R186.2, S39.2 (WIPER)
unnamed: R186.1, U44.2 (IN-)
unnamed: R188.1, U45.6 (OUT)
unnamed: R190.1, S40.2 (WIPER)
unnamed: R190.2, U45.2 (IN-)
unnamed: R192.2, U45.3 (IN+)
unnamed: R191.1, U44.6 (OUT)
unnamed: R194.1, U44.8 (SHDN)
unnamed: R187.2, U44.3 (IN+)
TF16: R188.2, R189.1, TO_FPGA_20.1; also elsewhere on the board

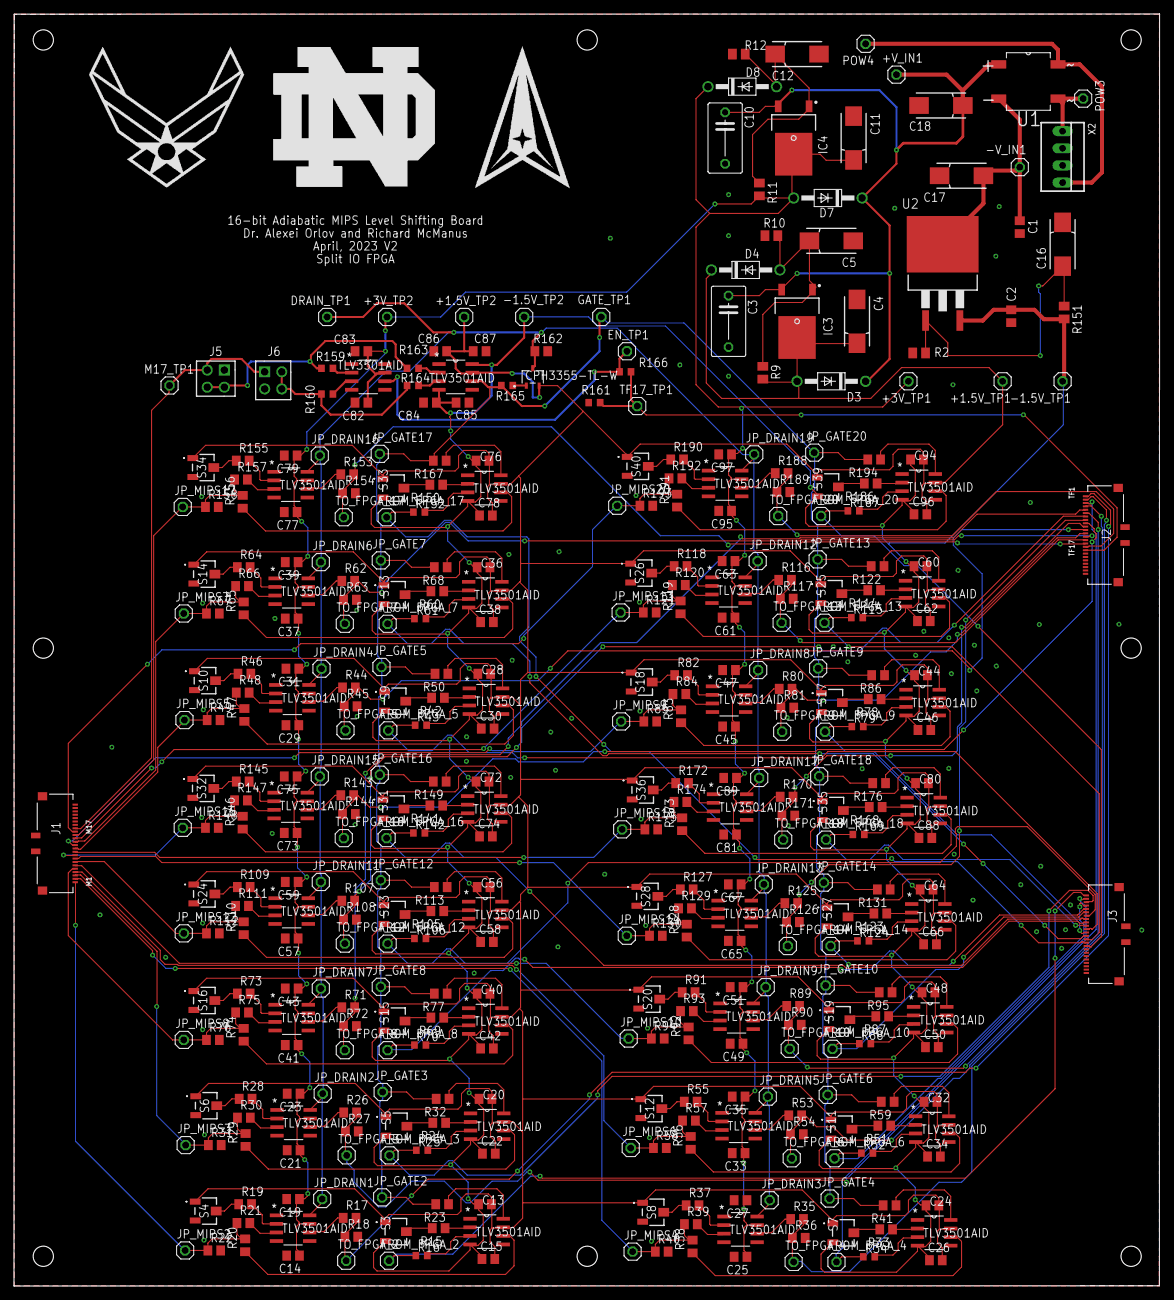
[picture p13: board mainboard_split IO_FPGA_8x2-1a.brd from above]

Board: 2 copper layers, 169.8 x 188.6 mm, 415 parts (0 on the bottom side), 215 nets.

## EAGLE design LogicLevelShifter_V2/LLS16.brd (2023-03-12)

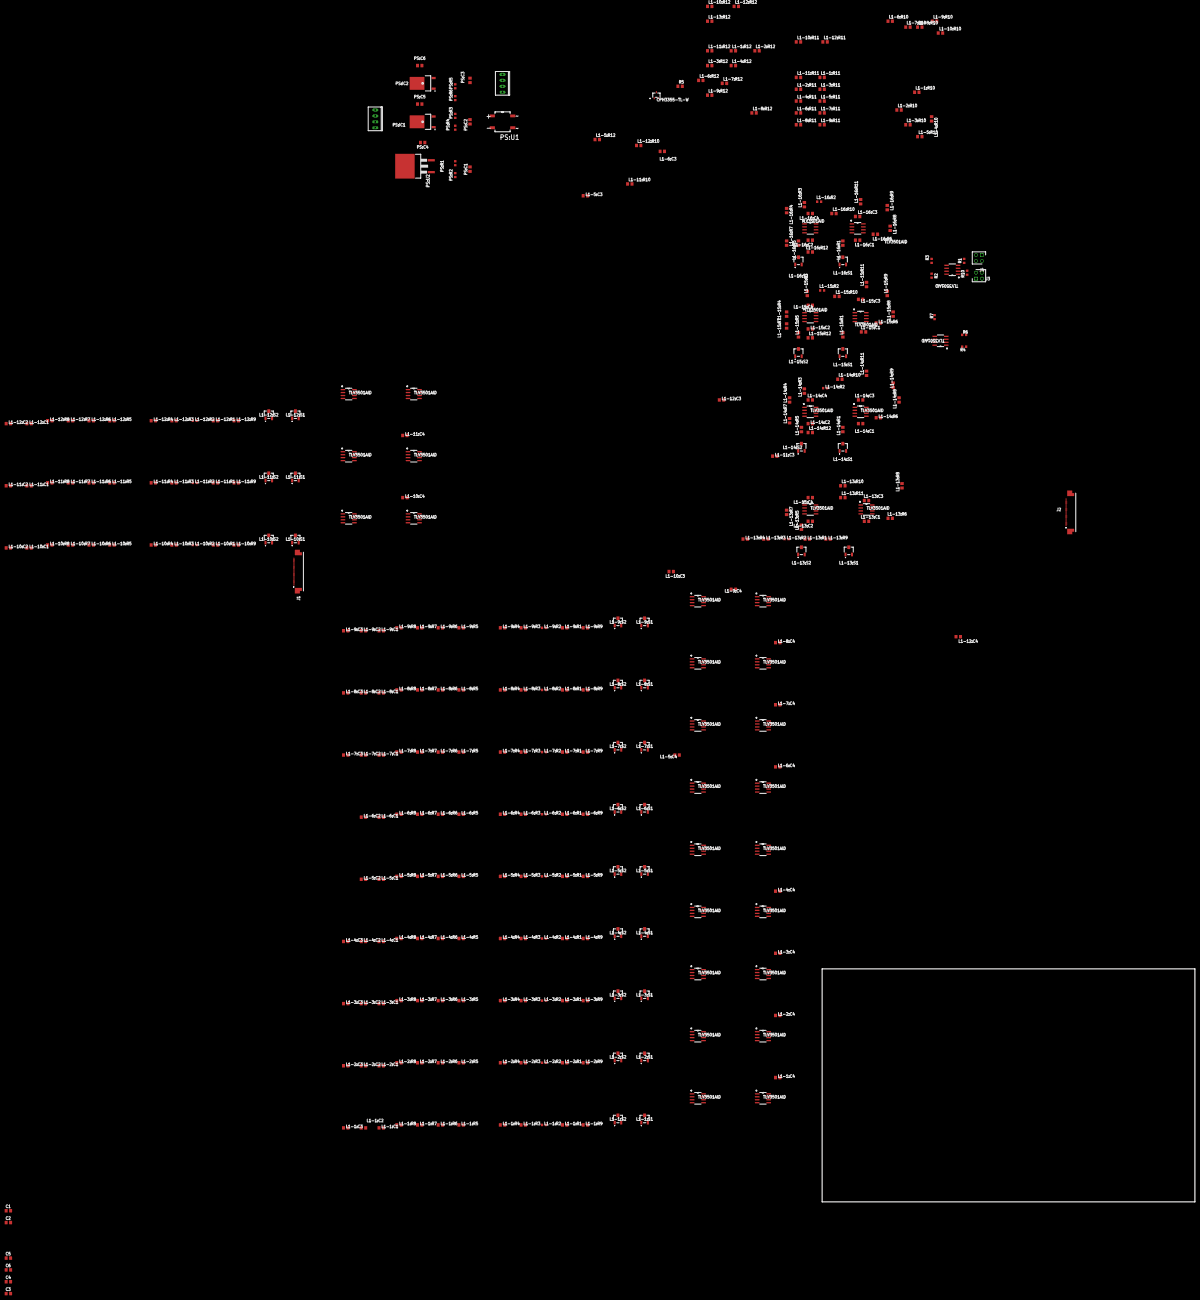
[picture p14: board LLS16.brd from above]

Board: 2 copper layers, 160.0 x 100.0 mm, 359 parts (0 on the bottom side), 264 nets, no tracks yet.

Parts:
C1, C2, C3, C4, C5, C6: C0805
J1, J2: 0524372471
J3, J4: 70287-1098; HDRV4W64P254_2X2_521X508X851P
L1-1:C1, L1-1:C2, L1-1:C3, L1-1:C4, L1-2:C1, L1-2:C2, L1-2:C3, L1-2:C4, L1-3:C1, L1-3:C2, L1-3:C3, L1-3:C4, L1-4:C1, L1-4:C2, L1-4:C3, L1-4:C4, L1-5:C1, L1-5:C2, L1-5:C3, L1-5:C4, L1-6:C1, L1-6:C2, L1-6:C3, L1-6:C4, L1-7:C1, L1-7:C2, L1-7:C3, L1-7:C4, L1-8:C1, L1-8:C2, L1-8:C3, L1-8:C4, L1-9:C1, L1-9:C2, L1-9:C3, L1-9:C4, L1-10:C1, L1-10:C2, L1-10:C3, L1-10:C4, L1-11:C1, L1-11:C2, L1-11:C3, L1-11:C4, L1-12:C1, L1-12:C2, L1-12:C3, L1-12:C4, L1-13:C1, L1-13:C2, L1-13:C3, L1-13:C4, L1-14:C1, L1-14:C2, L1-14:C3, L1-14:C4, L1-15:C1, L1-15:C2, L1-15:C3, L1-15:C4, L1-16:C1, L1-16:C2, L1-16:C3, L1-16:C4: C0805
L1-1:R1, L1-1:R5, L1-1:R7, L1-2:R1, L1-2:R5, L1-2:R7, L1-3:R1, L1-3:R5, L1-3:R7, L1-4:R1, L1-4:R5, L1-4:R7, L1-5:R1, L1-5:R5, L1-5:R7, L1-6:R1, L1-6:R5, L1-6:R7, L1-7:R1, L1-7:R5, L1-7:R7, L1-8:R1, L1-8:R5, L1-8:R7, L1-9:R1, L1-9:R5, L1-9:R7, L1-10:R1, L1-10:R5, L1-10:R7, L1-11:R1, L1-11:R5, L1-11:R7, L1-12:R1, L1-12:R5, L1-12:R7, L1-13:R1, L1-13:R5, L1-13:R7, L1-14:R1, L1-14:R5, L1-14:R7, L1-15:R1, L1-15:R5, L1-15:R7, L1-16:R1, L1-16:R5, L1-16:R7: 130; R0805
L1-1:R2, L1-2:R2, L1-3:R2, L1-4:R2, L1-5:R2, L1-6:R2, L1-7:R2, L1-8:R2, L1-9:R2, L1-10:R2, L1-11:R2, L1-12:R2, L1-13:R2, L1-14:R2, L1-15:R2, L1-16:R2: 130; R0603
L1-1:R3, L1-1:R4, L1-1:R6, L1-1:R8, L1-1:R9, L1-2:R3, L1-2:R4, L1-2:R6, L1-2:R8, L1-2:R9, L1-3:R3, L1-3:R4, L1-3:R6, L1-3:R8, L1-3:R9, L1-4:R3, L1-4:R4, L1-4:R6, L1-4:R8, L1-4:R9, L1-5:R3, L1-5:R4, L1-5:R6, L1-5:R8, L1-5:R9, L1-6:R3, L1-6:R4, L1-6:R6, L1-6:R8, L1-6:R9, L1-7:R3, L1-7:R4, L1-7:R6, L1-7:R8, L1-7:R9, L1-8:R3, L1-8:R4, L1-8:R6, L1-8:R8, L1-8:R9, L1-9:R3, L1-9:R4, L1-9:R6, L1-9:R8, L1-9:R9, L1-10:R3, L1-10:R4, L1-10:R6, L1-10:R8, L1-10:R9, L1-11:R3, L1-11:R4, L1-11:R6, L1-11:R8, L1-11:R9, L1-12:R3, L1-12:R4, L1-12:R6, L1-12:R8, L1-12:R9, L1-13:R3, L1-13:R4, L1-13:R6, L1-13:R8, L1-13:R9, L1-14:R3, L1-14:R4, L1-14:R6, L1-14:R8, L1-14:R9, L1-15:R3, L1-15:R4, L1-15:R6, L1-15:R8, L1-15:R9, L1-16:R3, L1-16:R4, L1-16:R6, L1-16:R8, L1-16:R9: 220; R0805
L1-1:R10, L1-1:R11, L1-1:R12, L1-2:R10, L1-2:R11, L1-2:R12, L1-3:R10, L1-3:R11, L1-3:R12, L1-4:R10, L1-4:R11, L1-4:R12, L1-5:R10, L1-5:R11, L1-5:R12, L1-6:R10, L1-6:R11, L1-6:R12, L1-7:R10, L1-7:R11, L1-7:R12, L1-8:R10, L1-8:R11, L1-8:R12, L1-9:R10, L1-9:R11, L1-9:R12, L1-10:R10, L1-10:R11, L1-10:R12, L1-11:R10, L1-11:R11, L1-11:R12, L1-12:R10, L1-12:R11, L1-12:R12, L1-13:R10, L1-13:R11, L1-13:R12, L1-14:R10, L1-14:R11, L1-14:R12, L1-15:R10, L1-15:R11, L1-15:R12, L1-16:R10, L1-16:R11, L1-16:R12: 0; R0805
L1-1:S1, L1-1:S2, L1-2:S1, L1-2:S2, L1-3:S1, L1-3:S2, L1-4:S1, L1-4:S2, L1-5:S1, L1-5:S2, L1-6:S1, L1-6:S2, L1-7:S1, L1-7:S2, L1-8:S1, L1-8:S2, L1-9:S1, L1-9:S2, L1-10:S1, L1-10:S2, L1-11:S1, L1-11:S2, L1-12:S1, L1-12:S2, L1-13:S1, L1-13:S2, L1-14:S1, L1-14:S2, L1-15:S1, L1-15:S2, L1-16:S1, L1-16:S2: SM-3TW102; SM3TW102
L1-1:U1, L1-1:U2, L1-2:U1, L1-2:U2, L1-3:U1, L1-3:U2, L1-4:U1, L1-4:U2, L1-5:U1, L1-5:U2, L1-6:U1, L1-6:U2, L1-7:U1, L1-7:U2, L1-8:U1, L1-8:U2, L1-9:U1, L1-9:U2, L1-10:U1, L1-10:U2, L1-11:U1, L1-11:U2, L1-12:U1, L1-12:U2, L1-13:U1, L1-13:U2, L1-14:U1, L1-14:U2, L1-15:U1, L1-15:U2, L1-16:U1, L1-16:U2: TLV3501AID; D8
PS:C1, PS:C2, PS:C3: 10uF; C0805
PS:C4, PS:C5, PS:C6: 0.1uF; C0805
PS:IC1, PS:IC2: LM317AMDT_NOPB; TO228P991X238-3N
PS:R1, PS:R3, PS:R5: 240; R0603
PS:R2, PS:R4, PS:R6: 49.9; R0603
PS:U1: DF10S; SOT508P985X260-4N
PS:U2: MC79GENERICD2T; D2PAK-3
R1, R2, R3, R4, R6, R7, R10: 220; R0603
R5: 51; R0805
U1: CPH3355-TL-W; CPH3_2P9X1P6_ONS
U2, U3: TLV3501AID; D8
U$1, U$2: CONNHEADERVERT4POS2.54MM

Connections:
+1.5V: C3.2, C4.2, L1-1:R11.2, L1-1:S1.3, L1-1:S2.1, L1-2:R11.2, L1-2:S1.3, L1-2:S2.1, L1-3:R11.2, L1-3:S1.3, L1-3:S2.1, L1-4:R11.2, L1-4:S1.3, L1-4:S2.1, L1-5:R11.2, L1-5:S1.3, L1-5:S2.1, L1-6:R11.2, L1-6:S1.3, L1-6:S2.1, L1-7:R11.2, L1-7:S1.3, L1-7:S2.1, L1-8:R11.2, L1-8:S1.3, L1-8:S2.1, L1-9:R11.2, L1-9:S1.3, L1-9:S2.1, L1-10:R11.2, L1-10:S1.3, L1-10:S2.1, L1-11:R11.2, L1-11:S1.3, L1-11:S2.1, L1-12:R11.2, L1-12:S1.3, L1-12:S2.1, L1-13:R11.2, L1-13:S1.3, L1-13:S2.1, L1-14:R11.2, L1-14:S1.3, L1-14:S2.1, L1-15:R11.2, L1-15:S1.3, L1-15:S2.1, L1-16:R11.2, L1-16:S1.3, L1-16:S2.1, PS:C5.1, PS:IC1.4, PS:R3.2, U1.2, U3.7, U$2.3
+3V: C1.2, C2.2, L1-1:R12.1, L1-2:R12.1, L1-3:R12.1, L1-4:R12.1, L1-5:R12.1, L1-6:R12.1, L1-7:R12.1, L1-8:R12.1, L1-9:R12.1, L1-10:R12.1, L1-11:R12.1, L1-12:R12.1, L1-13:R12.1, L1-14:R12.1, L1-15:R12.1, L1-16:R12.1, PS:C6.1, PS:IC2.4, PS:R5.2, U2.7, U$2.4
+5V: PS:U1.4, U$1.4
-1.5V: C5.1, C6.1, L1-1:R10.1, L1-1:S1.1, L1-2:R10.1, L1-2:S1.1, L1-3:R10.1, L1-3:S1.1, L1-4:R10.1, L1-4:S1.1, L1-5:R10.1, L1-5:S1.1, L1-6:R10.1, L1-6:S1.1, L1-7:R10.1, L1-7:S1.1, L1-8:R10.1, L1-8:S1.1, L1-9:R10.1, L1-9:S1.1, L1-10:R10.1, L1-10:S1.1, L1-11:R10.1, L1-11:S1.1, L1-12:R10.1, L1-12:S1.1, L1-13:R10.1, L1-13:S1.1, L1-14:R10.1, L1-14:S1.1, L1-15:R10.1, L1-15:S1.1, L1-16:R10.1, L1-16:S1.1, U3.4, U3.8, U$2.1
D: L1-1:U2.8, L1-2:U2.8, L1-3:U2.8, L1-4:U2.8, L1-5:U2.8, L1-6:U2.8, L1-7:U2.8, L1-8:U2.8, L1-9:U2.8, L1-10:U2.8, L1-11:U2.8, L1-12:U2.8, L1-13:U2.8, L1-14:U2.8, L1-15:U2.8, L1-16:U2.8, R5.1, U1.3
F1: J1.1, L1-1:R2.1, L1-1:R3.2, L1-1:R4.1
F2: J1.2, L1-2:R2.1, L1-2:R3.2, L1-2:R4.1
F3: J1.3, L1-3:R2.1, L1-3:R3.2, L1-3:R4.1
F4: J1.4, L1-4:R2.1, L1-4:R3.2, L1-4:R4.1
F5: J1.5, L1-5:R2.1, L1-5:R3.2, L1-5:R4.1
F6: J1.6, L1-6:R2.1, L1-6:R3.2, L1-6:R4.1
F7: J1.7, L1-7:R2.1, L1-7:R3.2, L1-7:R4.1
F8: J1.8, L1-8:R2.1, L1-8:R3.2, L1-8:R4.1
F9: J1.9, L1-9:R2.1, L1-9:R3.2, L1-9:R4.1
F10: J1.10, L1-10:R2.1, L1-10:R3.2, L1-10:R4.1
F11: J1.11, L1-11:R2.1, L1-11:R3.2, L1-11:R4.1
F12: J1.12, L1-12:R2.1, L1-12:R3.2, L1-12:R4.1
F13: J1.13, L1-13:R2.1, L1-13:R3.2, L1-13:R4.1
F14: J1.14, L1-14:R2.1, L1-14:R3.2, L1-14:R4.1
F15: J1.15, L1-15:R2.1, L1-15:R3.2, L1-15:R4.1
F16: J1.16, L1-16:R2.1, L1-16:R3.2, L1-16:R4.1
F17: J1.17, R2.2, R3.2
G: L1-1:R9.2, L1-2:R9.2, L1-3:R9.2, L1-4:R9.2, L1-5:R9.2, L1-6:R9.2, L1-7:R9.2, L1-8:R9.2, L1-9:R9.2, L1-10:R9.2, L1-11:R9.2, L1-12:R9.2, L1-13:R9.2, L1-14:R9.2, L1-15:R9.2, L1-16:R9.2, R7.1, U3.6
GND: C1.1, C2.1, C3.1, C4.1, C5.2, C6.2, J3.1, J4.3, PS:C1.2, PS:C2.2, PS:C3.2, PS:C4.2, PS:C5.2, PS:C6.2, PS:R2.1, PS:R4.1, PS:R6.1, R2.1, R5.2, U2.4, U2.8, U$1.2, U$1.3, U$2.2
L1-1:GND!: L1-1:C2.2, L1-1:C4.2, L1-1:R4.2, L1-1:R8.2, L1-1:S2.3, L1-1:U2.4
L1-1:N$1: L1-1:R1.2, L1-1:S1.2
L1-1:N$2: L1-1:R1.1, L1-1:U1.2
L1-1:N$3: L1-1:R2.2, L1-1:U1.3
L1-1:N$4: L1-1:C1.1, L1-1:C3.1, L1-1:R10.2, L1-1:U1.4
L1-1:N$5: L1-1:R3.1, L1-1:U2.6
L1-1:N$6: L1-1:R5.1, L1-1:S2.2
L1-1:N$7: L1-1:R5.2, L1-1:U2.2
L1-1:N$8: L1-1:R7.2, L1-1:U2.3
L1-1:N$9: L1-1:C1.2, L1-1:C3.2, L1-1:R11.1, L1-1:U1.7
L1-1:N$10: L1-1:R6.1, L1-1:U1.6
L1-1:N$11: L1-1:R9.1, L1-1:U1.8
L1-1:N$12: L1-1:C2.1, L1-1:C4.1, L1-1:R12.2, L1-1:U2.7
L1-2:GND!: L1-2:C2.2, L1-2:C4.2, L1-2:R4.2, L1-2:R8.2, L1-2:S2.3, L1-2:U2.4
L1-2:N$1: L1-2:R1.2, L1-2:S1.2
L1-2:N$2: L1-2:R1.1, L1-2:U1.2
L1-2:N$3: L1-2:R2.2, L1-2:U1.3
L1-2:N$4: L1-2:C1.1, L1-2:C3.1, L1-2:R10.2, L1-2:U1.4
L1-2:N$5: L1-2:R3.1, L1-2:U2.6
L1-2:N$6: L1-2:R5.1, L1-2:S2.2
L1-2:N$7: L1-2:R5.2, L1-2:U2.2
L1-2:N$8: L1-2:R7.2, L1-2:U2.3
L1-2:N$9: L1-2:C1.2, L1-2:C3.2, L1-2:R11.1, L1-2:U1.7
L1-2:N$10: L1-2:R6.1, L1-2:U1.6
L1-2:N$11: L1-2:R9.1, L1-2:U1.8
L1-2:N$12: L1-2:C2.1, L1-2:C4.1, L1-2:R12.2, L1-2:U2.7
L1-3:GND!: L1-3:C2.2, L1-3:C4.2, L1-3:R4.2, L1-3:R8.2, L1-3:S2.3, L1-3:U2.4
L1-3:N$1: L1-3:R1.2, L1-3:S1.2
L1-3:N$2: L1-3:R1.1, L1-3:U1.2
L1-3:N$3: L1-3:R2.2, L1-3:U1.3
L1-3:N$4: L1-3:C1.1, L1-3:C3.1, L1-3:R10.2, L1-3:U1.4
L1-3:N$5: L1-3:R3.1, L1-3:U2.6
L1-3:N$6: L1-3:R5.1, L1-3:S2.2
L1-3:N$7: L1-3:R5.2, L1-3:U2.2
L1-3:N$8: L1-3:R7.2, L1-3:U2.3
L1-3:N$9: L1-3:C1.2, L1-3:C3.2, L1-3:R11.1, L1-3:U1.7
L1-3:N$10: L1-3:R6.1, L1-3:U1.6
L1-3:N$11: L1-3:R9.1, L1-3:U1.8
L1-3:N$12: L1-3:C2.1, L1-3:C4.1, L1-3:R12.2, L1-3:U2.7
L1-4:GND!: L1-4:C2.2, L1-4:C4.2, L1-4:R4.2, L1-4:R8.2, L1-4:S2.3, L1-4:U2.4
L1-4:N$1: L1-4:R1.2, L1-4:S1.2
L1-4:N$2: L1-4:R1.1, L1-4:U1.2
L1-4:N$3: L1-4:R2.2, L1-4:U1.3
L1-4:N$4: L1-4:C1.1, L1-4:C3.1, L1-4:R10.2, L1-4:U1.4
L1-4:N$5: L1-4:R3.1, L1-4:U2.6
L1-4:N$6: L1-4:R5.1, L1-4:S2.2
L1-4:N$7: L1-4:R5.2, L1-4:U2.2
L1-4:N$8: L1-4:R7.2, L1-4:U2.3
L1-4:N$9: L1-4:C1.2, L1-4:C3.2, L1-4:R11.1, L1-4:U1.7
L1-4:N$10: L1-4:R6.1, L1-4:U1.6
L1-4:N$11: L1-4:R9.1, L1-4:U1.8
L1-4:N$12: L1-4:C2.1, L1-4:C4.1, L1-4:R12.2, L1-4:U2.7
L1-5:GND!: L1-5:C2.2, L1-5:C4.2, L1-5:R4.2, L1-5:R8.2, L1-5:S2.3, L1-5:U2.4
L1-5:N$1: L1-5:R1.2, L1-5:S1.2
L1-5:N$2: L1-5:R1.1, L1-5:U1.2
L1-5:N$3: L1-5:R2.2, L1-5:U1.3
L1-5:N$4: L1-5:C1.1, L1-5:C3.1, L1-5:R10.2, L1-5:U1.4
L1-5:N$5: L1-5:R3.1, L1-5:U2.6
L1-5:N$6: L1-5:R5.1, L1-5:S2.2
L1-5:N$7: L1-5:R5.2, L1-5:U2.2
L1-5:N$8: L1-5:R7.2, L1-5:U2.3
L1-5:N$9: L1-5:C1.2, L1-5:C3.2, L1-5:R11.1, L1-5:U1.7
L1-5:N$10: L1-5:R6.1, L1-5:U1.6
L1-5:N$11: L1-5:R9.1, L1-5:U1.8
L1-5:N$12: L1-5:C2.1, L1-5:C4.1, L1-5:R12.2, L1-5:U2.7
L1-6:GND!: L1-6:C2.2, L1-6:C4.2, L1-6:R4.2, L1-6:R8.2, L1-6:S2.3, L1-6:U2.4
L1-6:N$1: L1-6:R1.2, L1-6:S1.2
L1-6:N$2: L1-6:R1.1, L1-6:U1.2
L1-6:N$3: L1-6:R2.2, L1-6:U1.3
L1-6:N$4: L1-6:C1.1, L1-6:C3.1, L1-6:R10.2, L1-6:U1.4
L1-6:N$5: L1-6:R3.1, L1-6:U2.6
L1-6:N$6: L1-6:R5.1, L1-6:S2.2
L1-6:N$7: L1-6:R5.2, L1-6:U2.2
L1-6:N$8: L1-6:R7.2, L1-6:U2.3
L1-6:N$9: L1-6:C1.2, L1-6:C3.2, L1-6:R11.1, L1-6:U1.7
L1-6:N$10: L1-6:R6.1, L1-6:U1.6
L1-6:N$11: L1-6:R9.1, L1-6:U1.8
L1-6:N$12: L1-6:C2.1, L1-6:C4.1, L1-6:R12.2, L1-6:U2.7
L1-7:GND!: L1-7:C2.2, L1-7:C4.2, L1-7:R4.2, L1-7:R8.2, L1-7:S2.3, L1-7:U2.4
L1-7:N$1: L1-7:R1.2, L1-7:S1.2
L1-7:N$2: L1-7:R1.1, L1-7:U1.2
L1-7:N$3: L1-7:R2.2, L1-7:U1.3
L1-7:N$4: L1-7:C1.1, L1-7:C3.1, L1-7:R10.2, L1-7:U1.4
L1-7:N$5: L1-7:R3.1, L1-7:U2.6
L1-7:N$6: L1-7:R5.1, L1-7:S2.2
L1-7:N$7: L1-7:R5.2, L1-7:U2.2
L1-7:N$8: L1-7:R7.2, L1-7:U2.3
L1-7:N$9: L1-7:C1.2, L1-7:C3.2, L1-7:R11.1, L1-7:U1.7
L1-7:N$10: L1-7:R6.1, L1-7:U1.6
L1-7:N$11: L1-7:R9.1, L1-7:U1.8
L1-7:N$12: L1-7:C2.1, L1-7:C4.1, L1-7:R12.2, L1-7:U2.7
L1-8:GND!: L1-8:C2.2, L1-8:C4.2, L1-8:R4.2, L1-8:R8.2, L1-8:S2.3, L1-8:U2.4
L1-8:N$1: L1-8:R1.2, L1-8:S1.2
L1-8:N$2: L1-8:R1.1, L1-8:U1.2
L1-8:N$3: L1-8:R2.2, L1-8:U1.3
L1-8:N$4: L1-8:C1.1, L1-8:C3.1, L1-8:R10.2, L1-8:U1.4
L1-8:N$5: L1-8:R3.1, L1-8:U2.6
L1-8:N$6: L1-8:R5.1, L1-8:S2.2
L1-8:N$7: L1-8:R5.2, L1-8:U2.2
L1-8:N$8: L1-8:R7.2, L1-8:U2.3
L1-8:N$9: L1-8:C1.2, L1-8:C3.2, L1-8:R11.1, L1-8:U1.7
L1-8:N$10: L1-8:R6.1, L1-8:U1.6
L1-8:N$11: L1-8:R9.1, L1-8:U1.8
L1-8:N$12: L1-8:C2.1, L1-8:C4.1, L1-8:R12.2, L1-8:U2.7
L1-9:GND!: L1-9:C2.2, L1-9:C4.2, L1-9:R4.2, L1-9:R8.2, L1-9:S2.3, L1-9:U2.4
L1-9:N$1: L1-9:R1.2, L1-9:S1.2
L1-9:N$2: L1-9:R1.1, L1-9:U1.2
L1-9:N$3: L1-9:R2.2, L1-9:U1.3
L1-9:N$4: L1-9:C1.1, L1-9:C3.1, L1-9:R10.2, L1-9:U1.4
L1-9:N$5: L1-9:R3.1, L1-9:U2.6
L1-9:N$6: L1-9:R5.1, L1-9:S2.2
L1-9:N$7: L1-9:R5.2, L1-9:U2.2
L1-9:N$8: L1-9:R7.2, L1-9:U2.3
L1-9:N$9: L1-9:C1.2, L1-9:C3.2, L1-9:R11.1, L1-9:U1.7
L1-9:N$10: L1-9:R6.1, L1-9:U1.6
L1-9:N$11: L1-9:R9.1, L1-9:U1.8
L1-9:N$12: L1-9:C2.1, L1-9:C4.1, L1-9:R12.2, L1-9:U2.7
L1-10:GND!: L1-10:C2.2, L1-10:C4.2, L1-10:R4.2, L1-10:R8.2, L1-10:S2.3, L1-10:U2.4
L1-10:N$1: L1-10:R1.2, L1-10:S1.2
L1-10:N$2: L1-10:R1.1, L1-10:U1.2
L1-10:N$3: L1-10:R2.2, L1-10:U1.3
L1-10:N$4: L1-10:C1.1, L1-10:C3.1, L1-10:R10.2, L1-10:U1.4
L1-10:N$5: L1-10:R3.1, L1-10:U2.6
L1-10:N$6: L1-10:R5.1, L1-10:S2.2
L1-10:N$7: L1-10:R5.2, L1-10:U2.2
L1-10:N$8: L1-10:R7.2, L1-10:U2.3
L1-10:N$9: L1-10:C1.2, L1-10:C3.2, L1-10:R11.1, L1-10:U1.7
L1-10:N$10: L1-10:R6.1, L1-10:U1.6
L1-10:N$11: L1-10:R9.1, L1-10:U1.8
L1-10:N$12: L1-10:C2.1, L1-10:C4.1, L1-10:R12.2, L1-10:U2.7
L1-11:GND!: L1-11:C2.2, L1-11:C4.2, L1-11:R4.2, L1-11:R8.2, L1-11:S2.3, L1-11:U2.4
L1-11:N$1: L1-11:R1.2, L1-11:S1.2
L1-11:N$2: L1-11:R1.1, L1-11:U1.2
L1-11:N$3: L1-11:R2.2, L1-11:U1.3
L1-11:N$4: L1-11:C1.1, L1-11:C3.1, L1-11:R10.2, L1-11:U1.4
L1-11:N$5: L1-11:R3.1, L1-11:U2.6
L1-11:N$6: L1-11:R5.1, L1-11:S2.2
L1-11:N$7: L1-11:R5.2, L1-11:U2.2
L1-11:N$8: L1-11:R7.2, L1-11:U2.3
L1-11:N$9: L1-11:C1.2, L1-11:C3.2, L1-11:R11.1, L1-11:U1.7
L1-11:N$10: L1-11:R6.1, L1-11:U1.6
L1-11:N$11: L1-11:R9.1, L1-11:U1.8
L1-11:N$12: L1-11:C2.1, L1-11:C4.1, L1-11:R12.2, L1-11:U2.7
L1-12:GND!: L1-12:C2.2, L1-12:C4.2, L1-12:R4.2, L1-12:R8.2, L1-12:S2.3, L1-12:U2.4
L1-12:N$1: L1-12:R1.2, L1-12:S1.2
L1-12:N$2: L1-12:R1.1, L1-12:U1.2
L1-12:N$3: L1-12:R2.2, L1-12:U1.3
L1-12:N$4: L1-12:C1.1, L1-12:C3.1, L1-12:R10.2, L1-12:U1.4
L1-12:N$5: L1-12:R3.1, L1-12:U2.6
L1-12:N$6: L1-12:R5.1, L1-12:S2.2
L1-12:N$7: L1-12:R5.2, L1-12:U2.2
L1-12:N$8: L1-12:R7.2, L1-12:U2.3
L1-12:N$9: L1-12:C1.2, L1-12:C3.2, L1-12:R11.1, L1-12:U1.7
L1-12:N$10: L1-12:R6.1, L1-12:U1.6
L1-12:N$11: L1-12:R9.1, L1-12:U1.8
L1-12:N$12: L1-12:C2.1, L1-12:C4.1, L1-12:R12.2, L1-12:U2.7
L1-13:GND!: L1-13:C2.2, L1-13:C4.2, L1-13:R4.2, L1-13:R8.2, L1-13:S2.3, L1-13:U2.4
L1-13:N$1: L1-13:R1.2, L1-13:S1.2
L1-13:N$2: L1-13:R1.1, L1-13:U1.2
L1-13:N$3: L1-13:R2.2, L1-13:U1.3
L1-13:N$4: L1-13:C1.1, L1-13:C3.1, L1-13:R10.2, L1-13:U1.4
L1-13:N$5: L1-13:R3.1, L1-13:U2.6
L1-13:N$6: L1-13:R5.1, L1-13:S2.2
L1-13:N$7: L1-13:R5.2, L1-13:U2.2
L1-13:N$8: L1-13:R7.2, L1-13:U2.3
L1-13:N$9: L1-13:C1.2, L1-13:C3.2, L1-13:R11.1, L1-13:U1.7
L1-13:N$10: L1-13:R6.1, L1-13:U1.6
L1-13:N$11: L1-13:R9.1, L1-13:U1.8
L1-13:N$12: L1-13:C2.1, L1-13:C4.1, L1-13:R12.2, L1-13:U2.7
L1-14:GND!: L1-14:C2.2, L1-14:C4.2, L1-14:R4.2, L1-14:R8.2, L1-14:S2.3, L1-14:U2.4
L1-14:N$1: L1-14:R1.2, L1-14:S1.2
L1-14:N$2: L1-14:R1.1, L1-14:U1.2
L1-14:N$3: L1-14:R2.2, L1-14:U1.3
L1-14:N$4: L1-14:C1.1, L1-14:C3.1, L1-14:R10.2, L1-14:U1.4
L1-14:N$5: L1-14:R3.1, L1-14:U2.6
L1-14:N$6: L1-14:R5.1, L1-14:S2.2
L1-14:N$7: L1-14:R5.2, L1-14:U2.2
L1-14:N$8: L1-14:R7.2, L1-14:U2.3
L1-14:N$9: L1-14:C1.2, L1-14:C3.2, L1-14:R11.1, L1-14:U1.7
L1-14:N$10: L1-14:R6.1, L1-14:U1.6
L1-14:N$11: L1-14:R9.1, L1-14:U1.8
L1-14:N$12: L1-14:C2.1, L1-14:C4.1, L1-14:R12.2, L1-14:U2.7
L1-15:GND!: L1-15:C2.2, L1-15:C4.2, L1-15:R4.2, L1-15:R8.2, L1-15:S2.3, L1-15:U2.4
L1-15:N$1: L1-15:R1.2, L1-15:S1.2
L1-15:N$2: L1-15:R1.1, L1-15:U1.2
L1-15:N$3: L1-15:R2.2, L1-15:U1.3
L1-15:N$4: L1-15:C1.1, L1-15:C3.1, L1-15:R10.2, L1-15:U1.4
L1-15:N$5: L1-15:R3.1, L1-15:U2.6
L1-15:N$6: L1-15:R5.1, L1-15:S2.2
L1-15:N$7: L1-15:R5.2, L1-15:U2.2
L1-15:N$8: L1-15:R7.2, L1-15:U2.3
L1-15:N$9: L1-15:C1.2, L1-15:C3.2, L1-15:R11.1, L1-15:U1.7
L1-15:N$10: L1-15:R6.1, L1-15:U1.6
L1-15:N$11: L1-15:R9.1, L1-15:U1.8
L1-15:N$12: L1-15:C2.1, L1-15:C4.1, L1-15:R12.2, L1-15:U2.7
L1-16:GND!: L1-16:C2.2, L1-16:C4.2, L1-16:R4.2, L1-16:R8.2, L1-16:S2.3, L1-16:U2.4
L1-16:N$1: L1-16:R1.2, L1-16:S1.2
L1-16:N$2: L1-16:R1.1, L1-16:U1.2
L1-16:N$3: L1-16:R2.2, L1-16:U1.3
L1-16:N$4: L1-16:C1.1, L1-16:C3.1, L1-16:R10.2, L1-16:U1.4
L1-16:N$5: L1-16:R3.1, L1-16:U2.6
L1-16:N$6: L1-16:R5.1, L1-16:S2.2
L1-16:N$7: L1-16:R5.2, L1-16:U2.2
L1-16:N$8: L1-16:R7.2, L1-16:U2.3
L1-16:N$9: L1-16:C1.2, L1-16:C3.2, L1-16:R11.1, L1-16:U1.7
L1-16:N$10: L1-16:R6.1, L1-16:U1.6
L1-16:N$11: L1-16:R9.1, L1-16:U1.8
L1-16:N$12: L1-16:C2.1, L1-16:C4.1, L1-16:R12.2, L1-16:U2.7
M1: J2.1, L1-1:R6.2, L1-1:R7.1, L1-1:R8.1
M2: J2.2, L1-2:R6.2, L1-2:R7.1, L1-2:R8.1
M3: J2.3, L1-3:R6.2, L1-3:R7.1, L1-3:R8.1
M4: J2.4, L1-4:R6.2, L1-4:R7.1, L1-4:R8.1
M5: J2.5, L1-5:R6.2, L1-5:R7.1, L1-5:R8.1
M6: J2.6, L1-6:R6.2, L1-6:R7.1, L1-6:R8.1
M7: J2.7, L1-7:R6.2, L1-7:R7.1, L1-7:R8.1
M8: J2.8, L1-8:R6.2, L1-8:R7.1, L1-8:R8.1
M9: J2.9, L1-9:R6.2, L1-9:R7.1, L1-9:R8.1
M10: J2.10, L1-10:R6.2, L1-10:R7.1, L1-10:R8.1
M11: J2.11, L1-11:R6.2, L1-11:R7.1, L1-11:R8.1
M12: J2.12, L1-12:R6.2, L1-12:R7.1, L1-12:R8.1
M13: J2.13, L1-13:R6.2, L1-13:R7.1, L1-13:R8.1
M14: J2.14, L1-14:R6.2, L1-14:R7.1, L1-14:R8.1
M15: J2.15, L1-15:R6.2, L1-15:R7.1, L1-15:R8.1
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

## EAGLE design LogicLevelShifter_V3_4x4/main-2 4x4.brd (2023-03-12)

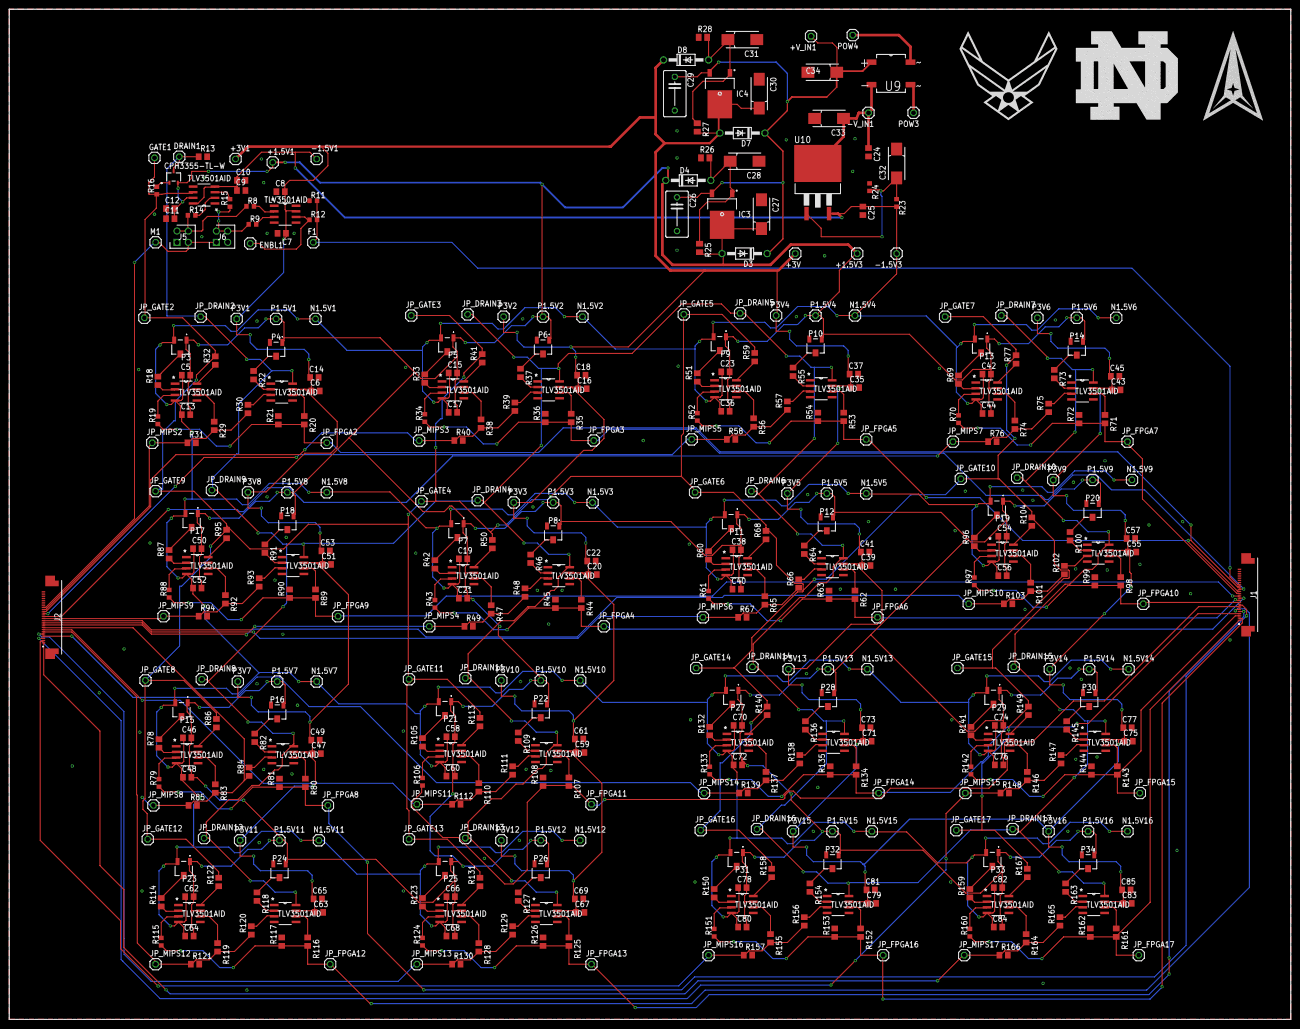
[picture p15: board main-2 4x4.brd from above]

Board: 2 copper layers, 289.1 x 227.8 mm, 445 parts (0 on the bottom side), 199 nets.

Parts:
+1.5V1, +1.5V3, +3V, +3V1: 1X01
+V_IN1: 1X01
-1.5V1, -1.5V3: 1X01
-V_IN1: 1X01
C5, C6, C7, C8, C9, C10, C11, C12, C13, C14, C15, C16, C17, C18, C19, C20, C21, C22, C23, C35, C36, C37, C38, C39, C40, C41, C42, C43, C44, C45, C46, C47, C48, C49, C50, C51, C52, C53, C54, C55, C56, C57, C58, C59, C60, C61, C62, C63, C64, C65, C66, C67, C68, C69, C70, C71, C72, C73, C74, C75, C76, C77, C78, C79, C80, C81, C82, C83, C84, C85: C0805
C24: 10uF; C0805
C25: 0.1uF; C0805
C26, C29: 0.1uF; C075-052X106
C27, C30, C32: 1uF; 085CS_1AR
C28, C31, C33, C34: 10uF; 085CS_1AR
D3, D4, D7, D8: 1N4002; DO41-10
DRAIN1: 1X01
ENBL1: 1X01
F1: 1X01
GATE1: 1X01
IC3, IC4: LM317AMDT_NOPB; TO228P991X238-3N
J1, J2: 0524372471
J5, J6: 70287-1098; HDRV4W64P254_2X2_521X508X851P
JP_DRAIN2, JP_DRAIN3, JP_DRAIN4, JP_DRAIN5, JP_DRAIN6, JP_DRAIN7, JP_DRAIN8, JP_DRAIN9, JP_DRAIN10, JP_DRAIN11, JP_DRAIN12, JP_DRAIN13, JP_DRAIN14, JP_DRAIN15, JP_DRAIN16, JP_DRAIN17: 1X01
JP_FPGA2, JP_FPGA3, JP_FPGA4, JP_FPGA5, JP_FPGA6, JP_FPGA7, JP_FPGA8, JP_FPGA9, JP_FPGA10, JP_FPGA11, JP_FPGA12, JP_FPGA13, JP_FPGA14, JP_FPGA15, JP_FPGA16, JP_FPGA17: 1X01
JP_GATE2, JP_GATE3, JP_GATE4, JP_GATE5, JP_GATE6, JP_GATE7, JP_GATE8, JP_GATE9, JP_GATE10, JP_GATE11, JP_GATE12, JP_GATE13, JP_GATE14, JP_GATE15, JP_GATE16, JP_GATE17: 1X01
JP_MIPS2, JP_MIPS3, JP_MIPS4, JP_MIPS5, JP_MIPS6, JP_MIPS7, JP_MIPS8, JP_MIPS9, JP_MIPS10, JP_MIPS11, JP_MIPS12, JP_MIPS13, JP_MIPS14, JP_MIPS15, JP_MIPS16, JP_MIPS17: 1X01
M1: 1X01
N1.5V1, N1.5V2, N1.5V3, N1.5V4, N1.5V5, N1.5V6, N1.5V7, N1.5V8, N1.5V9, N1.5V10, N1.5V11, N1.5V12, N1.5V13, N1.5V14, N1.5V15, N1.5V16: 1X01
P1.5V1, P1.5V2, P1.5V3, P1.5V4, P1.5V5, P1.5V6, P1.5V7, P1.5V8, P1.5V9, P1.5V10, P1.5V11, P1.5V12, P1.5V13, P1.5V14, P1.5V15, P1.5V16, P3V1, P3V2, P3V3, P3V4, P3V5, P3V6, P3V7, P3V8, P3V9, P3V10, P3V11, P3V12, P3V13, P3V14, P3V15, P3V16: 1X01
P3, P4, P5, P6, P7, P8, P9, P10, P11, P12, P13, P14, P15, P16, P17, P18, P19, P20, P21, P22, P23, P24, P25, P26, P27, P28, P29, P30, P31, P32, P33, P34: SM-3TW102; SM3TW102
POW3, POW4: 1X01
R8, R9, R11, R12, R14, R15, R16: 220; R0603
R13: 51; R0805
R18, R22, R30, R33, R37, R39, R42, R46, R48, R51, R55, R57, R60, R64, R66, R69, R73, R75, R78, R82, R84, R87, R91, R93, R96, R100, R102, R105, R109, R111, R114, R118, R120, R123, R127, R129, R132, R136, R138, R141, R145, R147, R150, R154, R156, R159, R163, R165: 130; R0805
R19, R34, R43, R52, R61, R70, R79, R88, R97, R106, R115, R124, R133, R142, R151, R160: 130; R0603
R20, R21, R29, R31, R32, R35, R36, R38, R40, R41, R44, R45, R47, R49, R50, R53, R54, R56, R58, R59, R62, R63, R65, R67, R68, R71, R72, R74, R76, R77, R80, R81, R83, R85, R86, R89, R90, R92, R94, R95, R98, R99, R101, R103, R104, R107, R108, R110, R112, R113, R116, R117, R119, R121, R122, R125, R126, R128, R130, R131, R134, R135, R137, R139, R140, R143, R144, R146, R148, R149, R152, R153, R155, R157, R158, R161, R162, R164, R166, R167: 220; R0805
R23: 240; R0603
R24: 49.9; R0603
R25, R27: 240Ω; M0805
R26: 49Ω; M0805
R28: 390Ω; M0805
U3, U5, U6, U7, U8, U11, U12, U13, U14, U15, U16, U17, U18, U19, U20, U21, U22, U23, U24, U25, U26, U27, U28, U29, U30, U31, U32, U33, U34, U35, U36, U37, U38, U39: TLV3501AID; D8
U4: CPH3355-TL-W; CPH3_2P9X1P6_ONS
U9: DF10S; SOT508P985X260-4N
U10: MC79GENERICD2T; D2PAK-3

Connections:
+1.5V: +1.5V1.1, +1.5V3.1, C5.2, C11.2, C12.2, C13.2, C15.2, C17.2, C19.2, C21.2, C23.2, C27.+, C36.2, C38.2, C40.2, C42.2, C44.2, C46.2, C48.2, C50.2, C52.2, C54.2, C56.2, C58.2, C60.2, C62.2, C64.2, C66.2, C68.2, C70.2, C72.2, C74.2, C76.2, C78.2, C80.2, C82.2, C84.2, D3.A, D4.C, IC3.4, P1.5V1.1, P1.5V2.1, P1.5V3.1, P1.5V4.1, P1.5V5.1, P1.5V6.1, P1.5V7.1, P1.5V8.1, P1.5V9.1, P1.5V10.1, P1.5V11.1, P1.5V12.1, P1.5V13.1, P1.5V14.1, P1.5V15.1, P1.5V16.1, P3.1, P4.1, P5.1, P6.1, P7.1, P8.1, P9.1, P10.1, P11.1, P12.1, P13.1, P14.1, P15.1, P16.1, P17.1, P18.1, P19.1, P20.1, P21.1, P22.1, P23.1, P24.1, P25.1, P26.1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
+3V: +3V.1, +3V1.1, C6.1, C7.2, C8.2, C14.1, C16.1, C18.1, C20.1, C22.1, C30.+, C35.1, C37.1, C39.1, C41.1, C43.1, C45.1, C47.1, C49.1, C51.1, C53.1, C55.1, C57.1, C59.1, C61.1, C63.1, C65.1, C67.1, C69.1, C71.1, C73.1, C75.1, C77.1, C79.1, C81.1, C83.1, C85.1, D7.A, D8.C, IC4.4, P3V1.1, P3V2.1, P3V3.1, P3V4.1, P3V5.1, P3V6.1, P3V7.1, P3V8.1, P3V9.1, P3V10.1, P3V11.1, P3V12.1, P3V13.1, P3V14.1, P3V15.1, P3V16.1, R27.2, U5.7, U7.7, U11.7, U13.7, U15.7, U17.7, U19.7, U21.7, U23.7, U25.7, U27.7, U29.7, U31.7, U33.7, U35.7, U37.7, U39.7
-1.5V: -1.5V1.1, -1.5V3.1, C5.1, C9.1, C10.1, C13.1, C15.1, C17.1, C19.1, C21.1, C23.1, C25.1, C36.1, C38.1, C40.1, C42.1, C44.1, C46.1, C48.1, C50.1, C52.1, C54.1, C56.1, C58.1, C60.1, C62.1, C64.1, C66.1, C68.1, C70.1, C72.1, C74.1, C76.1, C78.1, C80.1, C82.1, C84.1, N1.5V1.1, N1.5V2.1, N1.5V3.1, N1.5V4.1, N1.5V5.1, N1.5V6.1, N1.5V7.1, N1.5V8.1, N1.5V9.1, N1.5V10.1, N1.5V11.1, N1.5V12.1, N1.5V13.1, N1.5V14.1, N1.5V15.1, N1.5V16.1, P3.3, P5.3, P7.3, P9.3, P11.3, P13.3, P15.3, P17.3, P19.3, P21.3, P23.3, P25.3, P27.3, P29.3, P31.3, P33.3, R23.2, U3.4, U6.4, U6.8, U8.4, U10.3, U12.4, U14.4, U16.4, U18.4, U20.4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
DIR_GATE: GATE1.1, JP_GATE2.1, JP_GATE3.1, JP_GATE4.1, JP_GATE5.1, JP_GATE6.1, JP_GATE7.1, JP_GATE8.1, JP_GATE9.1, JP_GATE10.1, JP_GATE11.1, JP_GATE12.1, JP_GATE13.1, JP_GATE14.1, JP_GATE15.1, JP_GATE16.1, JP_GATE17.1, R16.1, R32.2, R41.2, R50.2, R59.2, R68.2, R77.2, R86.2, R95.2, R104.2, R113.2, R122.2, R131.2, R140.2, R149.2, R158.2, R167.2, U6.6
F1: J1.1, JP_FPGA17.1, R160.1, R161.2, R162.1
F2: J1.2, JP_FPGA16.1, R151.1, R152.2, R153.1
F3: J1.3, JP_FPGA15.1, R142.1, R143.2, R144.1
F4: J1.4, JP_FPGA14.1, R133.1, R134.2, R135.1
F5: J1.5, JP_FPGA13.1, R124.1, R125.2, R126.1
F6: J1.6, JP_FPGA12.1, R115.1, R116.2, R117.1
F7: J1.7, JP_FPGA11.1, R106.1, R107.2, R108.1
F8: J1.8, JP_FPGA8.1, R79.1, R80.2, R81.1
F9: J1.9, JP_FPGA10.1, R97.1, R98.2, R99.1
F10: J1.10, JP_FPGA6.1, R61.1, R62.2, R63.1
F11: J1.11, JP_FPGA4.1, R43.1, R44.2, R45.1
F12: J1.12, JP_FPGA9.1, R88.1, R89.2, R90.1
F13: J1.13, JP_FPGA7.1, R70.1, R71.2, R72.1
F14: J1.14, JP_FPGA5.1, R52.1, R53.2, R54.1
F15: J1.15, JP_FPGA3.1, R34.1, R35.2, R36.1
F16: J1.16, JP_FPGA2.1, R19.1, R20.2, R21.1
F17: F1.1, J1.17, R11.2, R12.2
GND: C6.2, C7.1, C8.1, C9.2, C10.2, C11.1, C12.1, C14.2, C16.2, C18.2, C20.2, C22.2, C24.2, C25.2, C26.2, C27.-, C28.-, C29.2, C30.-, C31.-, C32.+, C33.+, C34.-, C35.2, C37.2, C39.2, C41.2, C43.2, C45.2, C47.2, C49.2, C51.2, C53.2, C55.2, C57.2, C59.2, C61.2, C63.2, C65.2, C67.2, C69.2, C71.2, C73.2, C75.2, C77.2, C79.2, C81.2, C83.2, C85.2, J1.MP1, J1.MP2, J1.MP3, J1.MP4, J2.MP1, J2.MP2, J2.MP3, J2.MP4, J5.1, J6.3, P4.3, P6.3, P8.3, P10.3, P12.3, P14.3, P16.3, P18.3, P20.3, P22.3, P24.3, P26.3, P28.3, P30.3, P32.3, P34.3, R11.1, R13.2, R21.2, R24.1, R26.1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
INPPOS1: +V_IN1.1, C26.1, C29.1, C34.+, D3.C, D7.C, IC3.3, IC4.3, U9.1
INV_DIR_DRAIN: DRAIN1.1, JP_DRAIN2.1, JP_DRAIN3.1, JP_DRAIN4.1, JP_DRAIN5.1, JP_DRAIN6.1, JP_DRAIN7.1, JP_DRAIN8.1, JP_DRAIN9.1, JP_DRAIN10.1, JP_DRAIN11.1, JP_DRAIN12.1, JP_DRAIN13.1, JP_DRAIN14.1, JP_DRAIN15.1, JP_DRAIN16.1, JP_DRAIN17.1, R13.1, U4.3, U7.8, U11.8, U13.8, U15.8, U17.8, U19.8, U21.8, U23.8, U25.8, U27.8, U29.8, U31.8, U33.8, U35.8, U37.8, U39.8
IN_2: POW3.1, U9.3
M1: J2.1, JP_MIPS17.1, R164.2, R165.1, R166.1
M2: J2.2, JP_MIPS16.1, R155.2, R156.1, R157.1
M3: J2.3, JP_MIPS15.1, R146.2, R147.1, R148.1
M4: J2.4, JP_MIPS14.1, R137.2, R138.1, R139.1
M5: J2.5, JP_MIPS13.1, R128.2, R129.1, R130.1
M6: J2.6, JP_MIPS12.1, R119.2, R120.1, R121.1
M7: J2.7, JP_MIPS11.1, R110.2, R111.1, R112.1
M8: J2.8, JP_MIPS8.1, R83.2, R84.1, R85.1
M9: J2.9, JP_MIPS10.1, R101.2, R102.1, R103.1
M10: J2.10, JP_MIPS6.1, R65.2, R66.1, R67.1
M11: J2.11, JP_MIPS4.1, R47.2, R48.1, R49.1
M12: J2.12, JP_MIPS9.1, R92.2, R93.1, R94.1
M13: J2.13, JP_MIPS7.1, R74.2, R75.1, R76.1
M14: J2.14, JP_MIPS5.1, R56.2, R57.1, R58.1
M15: J2.15, JP_MIPS3.1, R38.2, R39.1, R40.1
M16: J2.16, JP_MIPS2.1, R29.2, R30.1, R31.1
M17: J2.17, J5.3, J6.1, M1.1
unnamed: P3.2, R18.2
unnamed: R18.1, U3.2
unnamed: R19.2, U3.3
unnamed: R20.1, U7.6
unnamed: P4.2, R22.1
unnamed: R22.2, U7.2
unnamed: R8.2, U5.2
unnamed: R30.2, U7.3
unnamed: R9.2, U5.3
unnamed: ENBL1.1, R12.1, U5.6
unnamed: J6.2, J6.4, R9.1, R15.1
unnamed: J5.2, J5.4, R8.1, R14.1
unnamed: R14.2, U6.2
unnamed: R15.2, U6.3
unnamed: R16.2, U4.1
unnamed: R29.1, U3.6
unnamed: R32.1, U3.8
unnamed: P5.2, R33.2
unnamed: R33.1, U8.2
unnamed: R34.2, U8.3
unnamed: C32.-, R23.1, R24.2, U10.1
unnamed: C28.+, D4.A, IC3.1, R25.1, R26.2
unnamed: C31.+, D8.A, IC4.1, R27.1, R28.2
unnamed: POW4.1, U9.4
unnamed: -V_IN1.1, C24.1, C33.-, U9.2, U10.4
unnamed: R35.1, U11.6
unnamed: P6.2, R37.1
unnamed: R37.2, U11.2
unnamed: R39.2, U11.3
unnamed: R38.1, U8.6
unnamed: R41.1, U8.8
unnamed: P7.2, R42.2
unnamed: R42.1, U12.2
unnamed: R43.2, U12.3
unnamed: R44.1, U13.6
unnamed: P8.2, R46.1
unnamed: R46.2, U13.2
unnamed: R48.2, U13.3
unnamed: R47.1, U12.6
unnamed: R50.1, U12.8
unnamed: P9.2, R51.2
unnamed: R51.1, U14.2
unnamed: R52.2, U14.3
unnamed: R53.1, U15.6
unnamed: P10.2, R55.1
unnamed: R55.2, U15.2
unnamed: R57.2, U15.3
unnamed: R56.1, U14.6
unnamed: R59.1, U14.8
unnamed: P11.2, R60.2
unnamed: R60.1, U16.2
unnamed: R61.2, U16.3
unnamed: R62.1, U17.6
unnamed: P12.2, R64.1
unnamed: R64.2, U17.2
unnamed: R66.2, U17.3
unnamed: R65.1, U16.6
unnamed: R68.1, U16.8
unnamed: P13.2, R69.2
unnamed: R69.1, U18.2
unnamed: R70.2, U18.3
unnamed: R71.1, U19.6
unnamed: P14.2, R73.1
unnamed: R73.2, U19.2
unnamed: R75.2, U19.3
unnamed: R74.1, U18.6
unnamed: R77.1, U18.8
unnamed: P15.2, R78.2
unnamed: R78.1, U20.2
unnamed: R79.2, U20.3
unnamed: R80.1, U21.6
unnamed: P16.2, R82.1
unnamed: R82.2, U21.2
unnamed: R84.2, U21.3
unnamed: R83.1, U20.6
unnamed: R86.1, U20.8
unnamed: P17.2, R87.2
unnamed: R87.1, U22.2
unnamed: R88.2, U22.3
unnamed: R89.1, U23.6
unnamed: P18.2, R91.1
unnamed: R91.2, U23.2
unnamed: R93.2, U23.3
unnamed: R92.1, U22.6
unnamed: R95.1, U22.8
unnamed: P19.2, R96.2
unnamed: R96.1, U24.2
unnamed: R97.2, U24.3
unnamed: R98.1, U25.6
unnamed: P20.2, R100.1
unnamed: R100.2, U25.2
unnamed: R102.2, U25.3
unnamed: R101.1, U24.6
unnamed: R104.1, U24.8
unnamed: P21.2, R105.2
unnamed: R105.1, U26.2
unnamed: R106.2, U26.3
unnamed: R107.1, U27.6
unnamed: P22.2, R109.1
unnamed: R109.2, U27.2
unnamed: R111.2, U27.3
unnamed: R110.1, U26.6
unnamed: R113.1, U26.8
unnamed: P23.2, R114.2
unnamed: R114.1, U28.2
unnamed: R115.2, U28.3
unnamed: R116.1, U29.6
unnamed: P24.2, R118.1
unnamed: R118.2, U29.2
unnamed: R120.2, U29.3
unnamed: R119.1, U28.6
unnamed: R122.1, U28.8
unnamed: P25.2, R123.2
unnamed: R123.1, U30.2
unnamed: R124.2, U30.3
unnamed: R125.1, U31.6
unnamed: P26.2, R127.1
unnamed: R127.2, U31.2
unnamed: R129.2, U31.3
unnamed: R128.1, U30.6
unnamed: R131.1, U30.8
unnamed: P27.2, R132.2
unnamed: R132.1, U32.2
unnamed: R133.2, U32.3
unnamed: R134.1, U33.6
unnamed: P28.2, R136.1
unnamed: R136.2, U33.2
unnamed: R138.2, U33.3
unnamed: R137.1, U32.6
unnamed: R140.1, U32.8
unnamed: P29.2, R141.2
unnamed: R141.1, U34.2
unnamed: R142.2, U34.3
unnamed: R143.1, U35.6
unnamed: P30.2, R145.1
unnamed: R145.2, U35.2
unnamed: R147.2, U35.3
unnamed: R146.1, U34.6
unnamed: R149.1, U34.8
unnamed: P31.2, R150.2
unnamed: R150.1, U36.2
unnamed: R151.2, U36.3
unnamed: R152.1, U37.6
unnamed: P32.2, R154.1
unnamed: R154.2, U37.2
unnamed: R156.2, U37.3
unnamed: R155.1, U36.6
unnamed: R158.1, U36.8
unnamed: P33.2, R159.2
unnamed: R159.1, U38.2
unnamed: R160.2, U38.3
unnamed: R161.1, U39.6
unnamed: P34.2, R163.1
unnamed: R163.2, U39.2
unnamed: R165.2, U39.3
unnamed: R164.1, U38.6
unnamed: R167.1, U38.8

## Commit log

2023-02-04 Add schematic and board files via upload
    [LLS16.brd, LLS16.sch]
2023-03-16 Approved warninigs
    [mainboard-01-8x2+1c.sch]

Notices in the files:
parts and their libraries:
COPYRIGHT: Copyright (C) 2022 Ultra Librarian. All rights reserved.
